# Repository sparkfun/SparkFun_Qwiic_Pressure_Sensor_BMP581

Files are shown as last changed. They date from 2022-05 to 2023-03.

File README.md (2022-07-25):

SparkFun Pressure Sensor - BMP581 (Qwiic) 
=========================================

<table class="table table-hover table-striped table-bordered">
  <tr align="center">
    <td><a href="https://www.sparkfun.com/products/20170">SparkFun Pressure Sensor - BMP581 (Qwiic)</a></td>
    <td><a href="https://www.sparkfun.com/products/20171">SparkFun Micro Pressure Sensor - BMP581 (Qwiic)</a></td>
  </tr>
  <tr align="center">
    <td><a href="https://www.sparkfun.com/products/20170"><i>SparkFun Pressure Sensor - BMP581 (Qwiic)</i></a></td>
    <td><a href="https://www.sparkfun.com/products/20171"><i>SparkFun Micro Pressure Sensor - BMP581 (Qwiic)</i></a></td>
  </tr>
</table>

The SparkFun Pressure Sensor - BMP581 (Qwiic) and Micro Pressure Sensor - BMP581 (Qwiic) features the BMP581 pressure sensor from Bosch Sensortec. The BMP581 boasts exceptional resolution (down to 1/64 Pa) and accuracy  and uses on-chip linearization and temperature compensation to provide true absolute data for pressure and temperature. 

The BMP581 has a wide pressure sensing range (30 to 125 kPa) with excellent accuracy across the sensing range (&plusmn; 0.5 hPa (max)) as well as output data rates up to 622 Hz. The sensor includes a configurable oversampling setting, FIFO buffer for storing up to 32 pressure samples, programmable low-pass filtering and even 6-bytes of user-programmable non-volatile memory. All of this allows you to customize the performance based on your application's requirements. Even without filtering, the BMP581 has very low noise (< 0.1Pa RMS).

Repository Contents
-------------------
* **/Documents** - Datasheet
* **/Hardware** - Eagle design files (.brd, .sch)
* **/Production** - Production panel files (.brd)

Documentation
-------------
* **[Hookup Guide](https://learn.sparkfun.com/tutorials/qwiic-pressure-sensor-bmp581-hookup-guide)** - Basic Hookup Guide for the SparkFun Pressure Sensor - BMP581 (Qwiic)
* **[BMP581 Arduino Library](https://github.com/sparkfun/SparkFun_BMP581_Arduino_Library)** - Arduino library for the BMP581 based off the Bosch API.

Product Versions
----------------
* [SEN-20170](https://www.sparkfun.com/products/20170) - Standard Size Initial Release.
* [SEN-20171](https://www.sparkfun.com/products/20171) - Micro Size Initial Release.

License Information
-------------------

This product is _**open source**_! 

Please review the LICENSE.md file for license information.

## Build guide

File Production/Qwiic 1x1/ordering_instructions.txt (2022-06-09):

panel size, 169x117mm
PCB thickness, 1.6mm
number of layers, 2
soldermask color, Red
silkscreen color, White
oz copper, 1oz
finish, HASL lead free
stencils, top
pcs per panel, 24
min trace width, 0.1778mm / 0.0070in
min drill size, 0.3048mm / 0.0120in

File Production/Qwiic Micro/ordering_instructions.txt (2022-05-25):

panel size, 79x170mm
PCB thickness, 1.6mm
number of layers, 2
soldermask color, Red
silkscreen color, White
oz copper, 1oz
finish, HASL lead free
stencils, top
pcs per panel, 64
min trace width, 0.1270mm / 0.0050in
min drill size, 0.3048mm / 0.0120in

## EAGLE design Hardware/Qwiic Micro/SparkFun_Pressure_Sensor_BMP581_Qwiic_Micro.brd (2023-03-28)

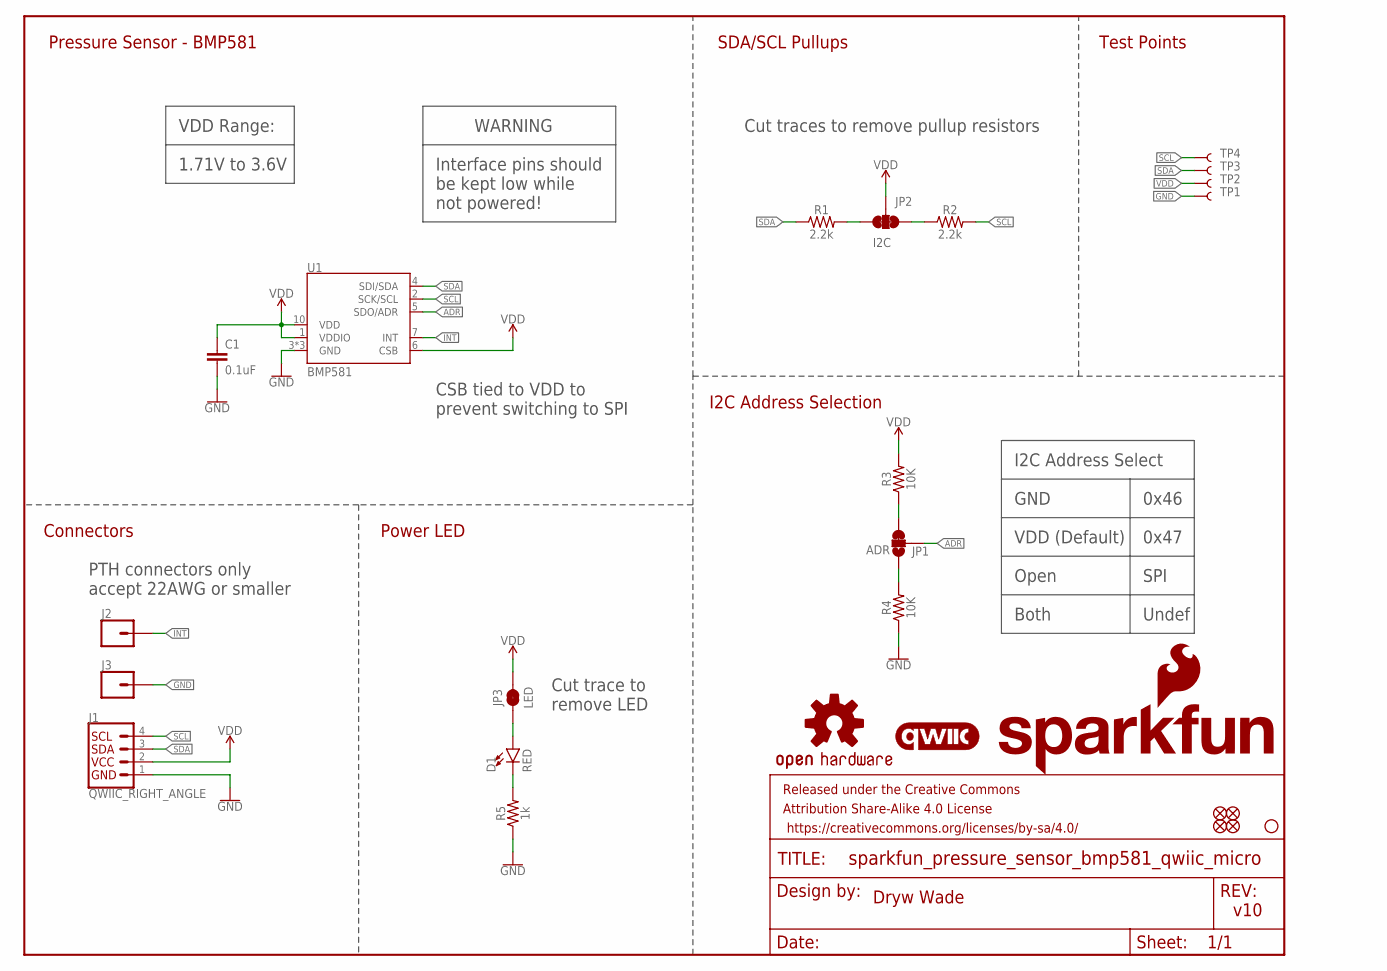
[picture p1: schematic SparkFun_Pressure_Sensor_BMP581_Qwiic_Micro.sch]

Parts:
C1: 0.1uF; 0402-TIGHT
D1: RED; LED-0402
FD1, FD2, FD3, FD4: FIDUCIALUFIDUCIAL; FIDUCIAL-MICRO
FRAME1: FRAME-LETTER; CREATIVE_COMMONS
H1: STAND-OFF
J1: QWIIC_RIGHT_ANGLE; JST04_1MM_RA
J2, J3: CONN_01_1MM; 1X01_1MM_NO_SILK
JP1: ADR; SMT-JUMPER_3_1-NC_TRACE_SILK
JP2: I2C; SMT-JUMPER_3_2-NC_TRACE_SILK
JP3: LED; SMT-JUMPER_2_NC_TRACE_SILK
LOGO1: OSHW-LOGOMINI; OSHW-LOGO-MINI
LOGO2: SFE_LOGO_FLAME.1_INCH; SFE_LOGO_FLAME_.1
LOGO3: QWIIC_LOGO_3MM; QWIIC_3MM
LOGO4: SFE_LOGO_NAMEBLANK; BLANK
R1, R2: 2.2k; 0402-TIGHT
R3, R4: 10K; 0402-TIGHT
R5: 1k; 0402-TIGHT
TP1, TP2, TP3, TP4: TEST-POINT3; PAD.03X.03
U1: BMP581

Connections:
ADR: JP1.2, U1.5 (SDO/ADR)
GND: C1.2, J1.1, J3.1, R4.1, R5.1, TP1.1, U1.3 (GND), U1.8 (GND), U1.9 (GND)
INT: J2.1, U1.7 (INT)
unnamed: JP1.3, R3.1
unnamed: JP1.1, R4.2
unnamed: JP2.1, R2.1
unnamed: JP2.3, R1.2
unnamed: D1.A, JP3.1
unnamed: D1.C, R5.2
SCL: J1.4, R2.2, TP4.1, U1.2 (SCK/SCL)
SDA: J1.3, R1.1, TP3.1, U1.4 (SDI/SDA)
VDD: C1.1, J1.2, JP2.2, JP3.2, R3.2, TP2.1, U1.1 (VDDIO), U1.6 (CSB), U1.10 (VDD)

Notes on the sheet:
Dryw Wade
v10
Pressure Sensor - BMP581
I2C Address Selection
I2C Address Select
GND
VDD (Default)
0x46
0x47
Open
Both
SPI
Undef
VDD Range:
1.71V to 3.6V
WARNING
Interface pins should be kept low while not powered!
Connectors
SDA/SCL Pullups
Cut traces to remove pullup resistors
Test Points
Power LED
Cut trace to remove LED
PTH connectors only accept 22AWG or smaller
CSB tied to VDD to prevent switching to SPI

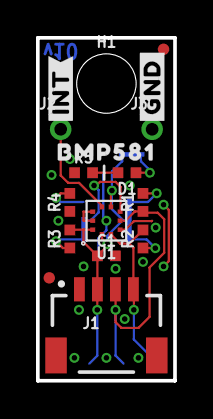
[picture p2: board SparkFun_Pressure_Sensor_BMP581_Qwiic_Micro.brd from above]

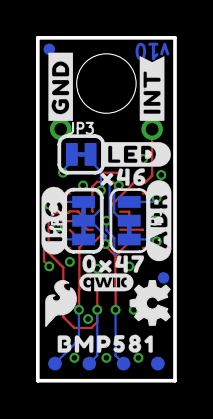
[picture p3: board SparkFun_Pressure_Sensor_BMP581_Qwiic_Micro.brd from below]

Board: 2 copper layers, 7.6 x 19.1 mm, 39 parts (20 on the bottom side), 12 nets.

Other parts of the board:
U$1, U$2: BMP5810
U$3: #I2C#0
U$4: #ADR#0
U$5, U$6: #GND#0
U$7, U$8: #INT#0
U$9: #LED#0
U$10: X460
U$11: 0X470

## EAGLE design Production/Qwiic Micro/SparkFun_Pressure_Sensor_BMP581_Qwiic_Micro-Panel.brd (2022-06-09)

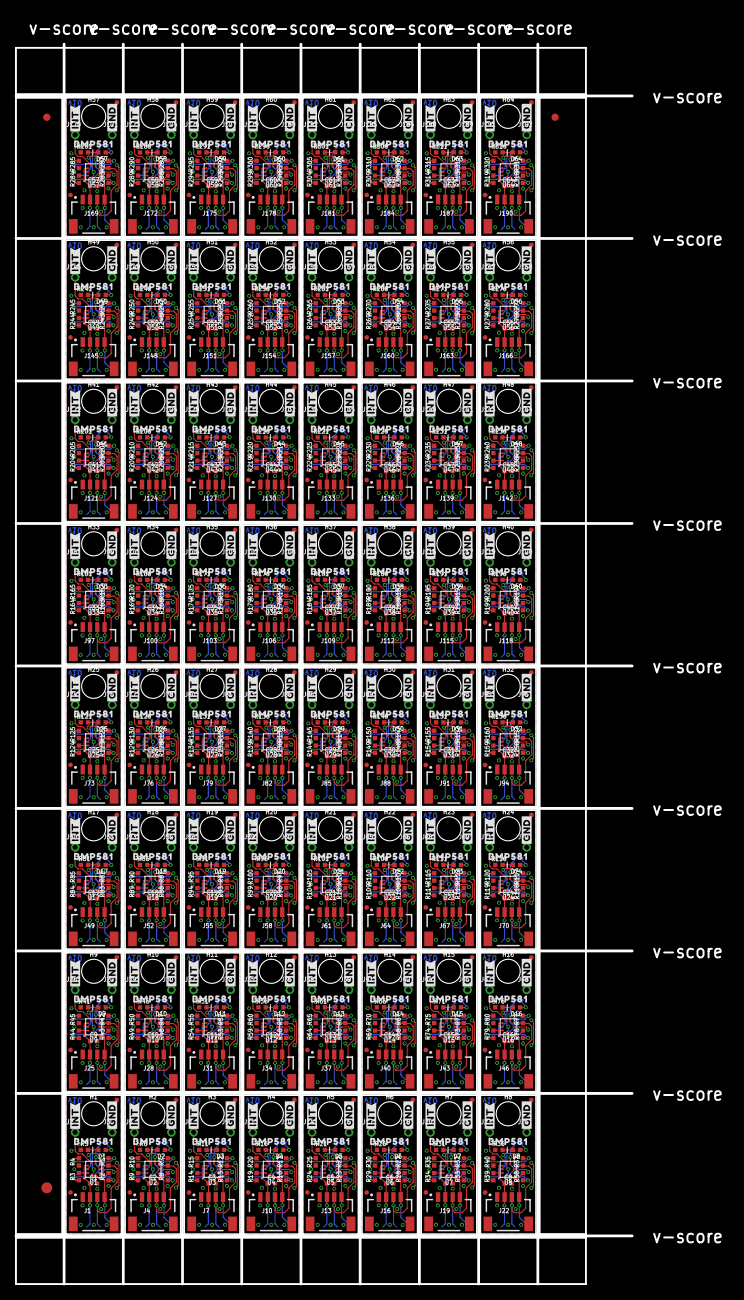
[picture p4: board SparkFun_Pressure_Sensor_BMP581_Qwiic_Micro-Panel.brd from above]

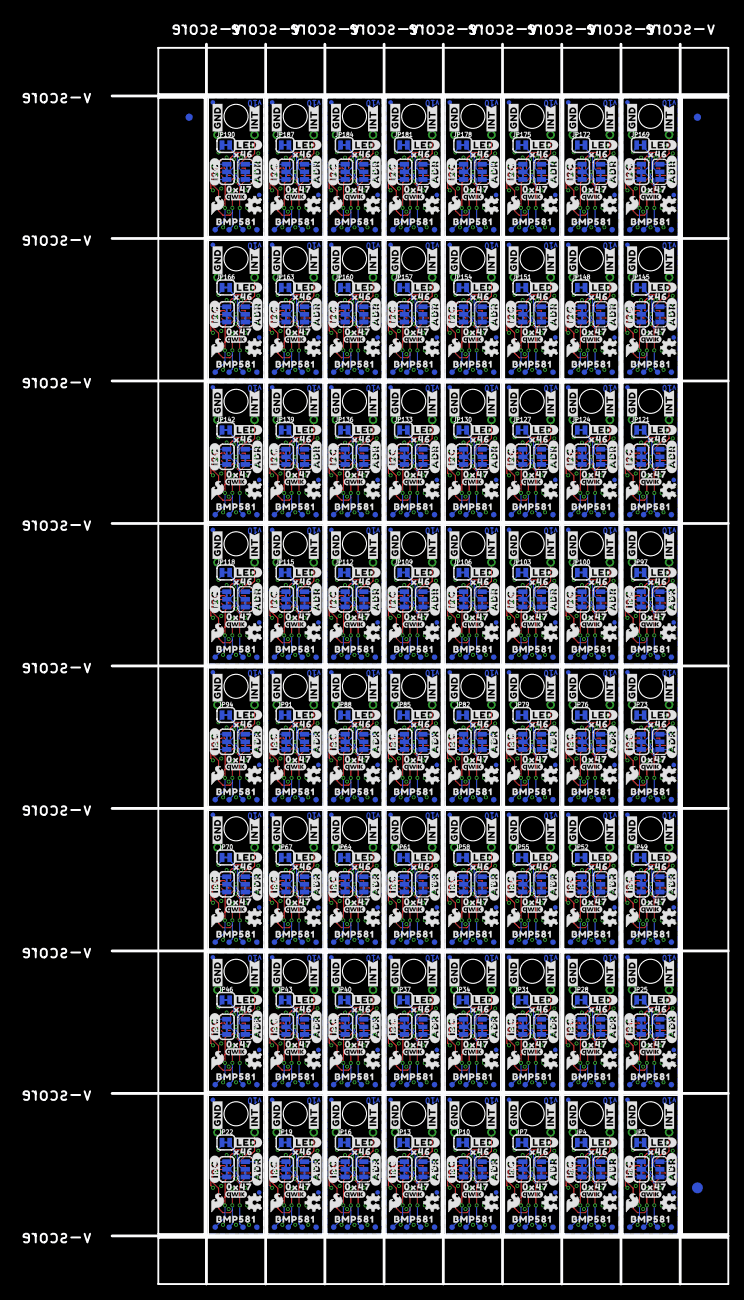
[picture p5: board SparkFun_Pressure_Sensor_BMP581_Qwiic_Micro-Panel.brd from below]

Board: 2 copper layers, 84.6 x 170.2 mm, 2502 parts (1283 on the bottom side), 768 nets.

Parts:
C1, C2, C3, C4, C5, C6, C7, C8, C9, C10, C11, C12, C13, C14, C15, C16, C17, C18, C19, C20, C21, C22, C23, C24, C25, C26, C27, C28, C29, C30, C31, C32, C33, C34, C35, C36, C37, C38, C39, C40, C41, C42, C43, C44, C45, C46, C47, C48, C49, C50, C51, C52, C53, C54, C55, C56, C57, C58, C59, C60, C61, C62, C63, C64: 0.1uF; 0402-TIGHT
D1, D2, D3, D4, D5, D6, D7, D8, D9, D10, D11, D12, D13, D14, D15, D16, D17, D18, D19, D20, D21, D22, D23, D24, D25, D26, D27, D28, D29, D30, D31, D32, D33, D34, D35, D36, D37, D38, D39, D40, D41, D42, D43, D44, D45, D46, D47, D48, D49, D50, D51, D52, D53, D54, D55, D56, D57, D58, D59, D60, D61, D62, D63, D64: RED; LED-0402
E$1, E$2, E$3, E$4: FIDUCIAL-1X2
E$5, E$6: FIDUCIAL-1.5X3
FD1, FD2, FD3, FD4, FD5, FD6, FD7, FD8, FD9, FD10, FD11, FD12, FD13, FD14, FD15, FD16, FD17, FD18, FD19, FD20, FD21, FD22, FD23, FD24, FD25, FD26, FD27, FD28, FD29, FD30, FD31, FD32, FD33, FD34, FD35, FD36, FD37, FD38, FD39, FD40, FD41, FD42, FD43, FD44, FD45, FD46, FD47, FD48, FD49, FD50, FD51, FD52, FD53, FD54, FD55, FD56, FD57, FD58, FD59, FD60, FD61, FD62, FD63, FD64, FD65, FD66, FD67, FD68, FD69, FD70, FD71, FD72, FD73, FD74, FD75, FD76, FD77, FD78, FD79, FD80, FD81, FD82, FD83, FD84, FD85, FD86, FD87, FD88, FD89, FD90, FD91, FD92, FD93, FD94, FD95, FD96, FD97, FD98, FD99, FD100, FD101, FD102, FD103, FD104, FD105, FD106, FD107, FD108, FD109, FD110, FD111, FD112, FD113, FD114, FD115, FD116, FD117, FD118, FD119, FD120, FD121, FD122, FD123, FD124, FD125, FD126, FD127, FD128, FD129, FD130, FD131, FD132, FD133, FD134, FD135, FD136, FD137, FD138, FD139, FD140, FD141, FD142, FD143, FD144, FD145, FD146, FD147, FD148, FD149, FD150, FD151, FD152, FD153, FD154, FD155, FD156, FD157, FD158, FD159, FD160, FD161, FD162, FD163, FD164, FD165, FD166, FD167, FD168, FD169, FD170, FD171, FD172, FD173, FD174, FD175, FD176, FD177, FD178, FD179, FD180, FD181, FD182, FD183, FD184, FD185, FD186, FD187, FD188, FD189, FD190, FD191, FD192, FD193, FD194, FD195, FD196, FD197, FD198, FD199, FD200, FD201, FD202, FD203, FD204, FD205, FD206, FD207, FD208, FD209, FD210, FD211, FD212, FD213, FD214, FD215, FD216, FD217, FD218, FD219, FD220, FD221, FD222, FD223, FD224, FD225, FD226, FD227, FD228, FD229, FD230, FD231, FD232, FD233, FD234, FD235, FD236, FD237, FD238, FD239, FD240, FD241, FD242, FD243, FD244, FD245, FD246, FD247, FD248, FD249, FD250, FD251, FD252, FD253, FD254, FD255, FD256: FIDUCIALUFIDUCIAL; FIDUCIAL-MICRO
FRAME1, FRAME2, FRAME3, FRAME4, FRAME5, FRAME6, FRAME7, FRAME8, FRAME9, FRAME10, FRAME11, FRAME12, FRAME13, FRAME14, FRAME15, FRAME16, FRAME17, FRAME18, FRAME19, FRAME20, FRAME21, FRAME22, FRAME23, FRAME24, FRAME25, FRAME26, FRAME27, FRAME28, FRAME29, FRAME30, FRAME31, FRAME32, FRAME33, FRAME34, FRAME35, FRAME36, FRAME37, FRAME38, FRAME39, FRAME40, FRAME41, FRAME42, FRAME43, FRAME44, FRAME45, FRAME46, FRAME47, FRAME48, FRAME49, FRAME50, FRAME51, FRAME52, FRAME53, FRAME54, FRAME55, FRAME56, FRAME57, FRAME58, FRAME59, FRAME60, FRAME61, FRAME62, FRAME63, FRAME64: FRAME-LETTER; CREATIVE_COMMONS
H1, H2, H3, H4, H5, H6, H7, H8, H9, H10, H11, H12, H13, H14, H15, H16, H17, H18, H19, H20, H21, H22, H23, H24, H25, H26, H27, H28, H29, H30, H31, H32, H33, H34, H35, H36, H37, H38, H39, H40, H41, H42, H43, H44, H45, H46, H47, H48, H49, H50, H51, H52, H53, H54, H55, H56, H57, H58, H59, H60, H61, H62, H63, H64: STAND-OFF
J1, J4, J7, J10, J13, J16, J19, J22, J25, J28, J31, J34, J37, J40, J43, J46, J49, J52, J55, J58, J61, J64, J67, J70, J73, J76, J79, J82, J85, J88, J91, J94, J97, J100, J103, J106, J109, J112, J115, J118, J121, J124, J127, J130, J133, J136, J139, J142, J145, J148, J151, J154, J157, J160, J163, J166, J169, J172, J175, J178, J181, J184, J187, J190: QWIIC_RIGHT_ANGLE; JST04_1MM_RA
J2, J3, J5, J6, J8, J9, J11, J12, J14, J15, J17, J18, J20, J21, J23, J24, J26, J27, J29, J30, J32, J33, J35, J36, J38, J39, J41, J42, J44, J45, J47, J48, J50, J51, J53, J54, J56, J57, J59, J60, J62, J63, J65, J66, J68, J69, J71, J72, J74, J75, J77, J78, J80, J81, J83, J84, J86, J87, J89, J90, J92, J93, J95, J96, J98, J99, J101, J102, J104, J105, J107, J108, J110, J111, J113, J114, J116, J117, J119, J120, J122, J123, J125, J126, J128, J129, J131, J132, J134, J135, J137, J138, J140, J141, J143, J144, J146, J147, J149, J150, J152, J153, J155, J156, J158, J159, J161, J162, J164, J165, J167, J168, J170, J171, J173, J174, J176, J177, J179, J180, J182, J183, J185, J186, J188, J189, J191, J192: 1X01_1MM_NO_SILK
JP1, JP6, JP9, JP12, JP15, JP18, JP21, JP24, JP27, JP30, JP33, JP36, JP39, JP42, JP45, JP48, JP51, JP54, JP57, JP60, JP63, JP66, JP69, JP72, JP75, JP78, JP81, JP84, JP87, JP90, JP93, JP96, JP99, JP102, JP105, JP108, JP111, JP114, JP117, JP120, JP123, JP126, JP129, JP132, JP135, JP138, JP141, JP144, JP147, JP150, JP153, JP156, JP159, JP162, JP165, JP168, JP171, JP174, JP177, JP180, JP183, JP186, JP189, JP192: ADR; SMT-JUMPER_3_1-NC_TRACE_SILK
JP2, JP5, JP8, JP11, JP14, JP17, JP20, JP23, JP26, JP29, JP32, JP35, JP38, JP41, JP44, JP47, JP50, JP53, JP56, JP59, JP62, JP65, JP68, JP71, JP74, JP77, JP80, JP83, JP86, JP89, JP92, JP95, JP98, JP101, JP104, JP107, JP110, JP113, JP116, JP119, JP122, JP125, JP128, JP131, JP134, JP137, JP140, JP143, JP146, JP149, JP152, JP155, JP158, JP161, JP164, JP167, JP170, JP173, JP176, JP179, JP182, JP185, JP188, JP191: I2C; SMT-JUMPER_3_2-NC_TRACE_SILK
JP3, JP4, JP7, JP10, JP13, JP16, JP19, JP22, JP25, JP28, JP31, JP34, JP37, JP40, JP43, JP46, JP49, JP52, JP55, JP58, JP61, JP64, JP67, JP70, JP73, JP76, JP79, JP82, JP85, JP88, JP91, JP94, JP97, JP100, JP103, JP106, JP109, JP112, JP115, JP118, JP121, JP124, JP127, JP130, JP133, JP136, JP139, JP142, JP145, JP148, JP151, JP154, JP157, JP160, JP163, JP166, JP169, JP172, JP175, JP178, JP181, JP184, JP187, JP190: LED; SMT-JUMPER_2_NC_TRACE_SILK
LOGO1, LOGO5, LOGO9, LOGO13, LOGO17, LOGO21, LOGO25, LOGO29, LOGO33, LOGO37, LOGO41, LOGO45, LOGO49, LOGO53, LOGO57, LOGO61, LOGO65, LOGO69, LOGO73, LOGO77, LOGO81, LOGO85, LOGO89, LOGO93, LOGO97, LOGO101, LOGO105, LOGO109, LOGO113, LOGO117, LOGO121, LOGO125, LOGO129, LOGO133, LOGO137, LOGO141, LOGO145, LOGO149, LOGO153, LOGO157, LOGO161, LOGO165, LOGO169, LOGO173, LOGO177, LOGO181, LOGO185, LOGO189, LOGO193, LOGO197, LOGO201, LOGO205, LOGO209, LOGO213, LOGO217, LOGO221, LOGO225, LOGO229, LOGO233, LOGO237, LOGO241, LOGO245, LOGO249, LOGO253: OSHW-LOGOMINI; OSHW-LOGO-MINI
LOGO2, LOGO6, LOGO10, LOGO14, LOGO18, LOGO22, LOGO26, LOGO30, LOGO34, LOGO38, LOGO42, LOGO46, LOGO50, LOGO54, LOGO58, LOGO62, LOGO66, LOGO70, LOGO74, LOGO78, LOGO82, LOGO86, LOGO90, LOGO94, LOGO98, LOGO102, LOGO106, LOGO110, LOGO114, LOGO118, LOGO122, LOGO126, LOGO130, LOGO134, LOGO138, LOGO142, LOGO146, LOGO150, LOGO154, LOGO158, LOGO162, LOGO166, LOGO170, LOGO174, LOGO178, LOGO182, LOGO186, LOGO190, LOGO194, LOGO198, LOGO202, LOGO206, LOGO210, LOGO214, LOGO218, LOGO222, LOGO226, LOGO230, LOGO234, LOGO238, LOGO242, LOGO246, LOGO250, LOGO254: SFE_LOGO_FLAME.1_INCH; SFE_LOGO_FLAME_.1
LOGO3, LOGO7, LOGO11, LOGO15, LOGO19, LOGO23, LOGO27, LOGO31, LOGO35, LOGO39, LOGO43, LOGO47, LOGO51, LOGO55, LOGO59, LOGO63, LOGO67, LOGO71, LOGO75, LOGO79, LOGO83, LOGO87, LOGO91, LOGO95, LOGO99, LOGO103, LOGO107, LOGO111, LOGO115, LOGO119, LOGO123, LOGO127, LOGO131, LOGO135, LOGO139, LOGO143, LOGO147, LOGO151, LOGO155, LOGO159, LOGO163, LOGO167, LOGO171, LOGO175, LOGO179, LOGO183, LOGO187, LOGO191, LOGO195, LOGO199, LOGO203, LOGO207, LOGO211, LOGO215, LOGO219, LOGO223, LOGO227, LOGO231, LOGO235, LOGO239, LOGO243, LOGO247, LOGO251, LOGO255: QWIIC_LOGO_3MM; QWIIC_3MM
LOGO4, LOGO8, LOGO12, LOGO16, LOGO20, LOGO24, LOGO28, LOGO32, LOGO36, LOGO40, LOGO44, LOGO48, LOGO52, LOGO56, LOGO60, LOGO64, LOGO68, LOGO72, LOGO76, LOGO80, LOGO84, LOGO88, LOGO92, LOGO96, LOGO100, LOGO104, LOGO108, LOGO112, LOGO116, LOGO120, LOGO124, LOGO128, LOGO132, LOGO136, LOGO140, LOGO144, LOGO148, LOGO152, LOGO156, LOGO160, LOGO164, LOGO168, LOGO172, LOGO176, LOGO180, LOGO184, LOGO188, LOGO192, LOGO196, LOGO200, LOGO204, LOGO208, LOGO212, LOGO216, LOGO220, LOGO224, LOGO228, LOGO232, LOGO236, LOGO240, LOGO244, LOGO248, LOGO252, LOGO256: SFE_LOGO_NAMEBLANK; BLANK
R1, R2, R7, R8, R12, R13, R17, R18, R22, R23, R27, R28, R32, R33, R37, R38, R42, R43, R47, R48, R52, R53, R57, R58, R62, R63, R67, R68, R72, R73, R77, R78, R82, R83, R87, R88, R92, R93, R97, R98, R102, R103, R107, R108, R112, R113, R117, R118, R122, R123, R127, R128, R132, R133, R137, R138, R142, R143, R147, R148, R152, R153, R157, R158, R162, R163, R167, R168, R172, R173, R177, R178, R182, R183, R187, R188, R192, R193, R197, R198, R202, R203, R207, R208, R212, R213, R217, R218, R222, R223, R227, R228, R232, R233, R237, R238, R242, R243, R247, R248, R252, R253, R257, R258, R262, R263, R267, R268, R272, R273, R277, R278, R282, R283, R287, R288, R292, R293, R297, R298, R302, R303, R307, R308, R312, R313, R317, R318: 2.2k; 0402-TIGHT
R3, R4, R9, R10, R14, R15, R19, R20, R24, R25, R29, R30, R34, R35, R39, R40, R44, R45, R49, R50, R54, R55, R59, R60, R64, R65, R69, R70, R74, R75, R79, R80, R84, R85, R89, R90, R94, R95, R99, R100, R104, R105, R109, R110, R114, R115, R119, R120, R124, R125, R129, R130, R134, R135, R139, R140, R144, R145, R149, R150, R154, R155, R159, R160, R164, R165, R169, R170, R174, R175, R179, R180, R184, R185, R189, R190, R194, R195, R199, R200, R204, R205, R209, R210, R214, R215, R219, R220, R224, R225, R229, R230, R234, R235, R239, R240, R244, R245, R249, R250, R254, R255, R259, R260, R264, R265, R269, R270, R274, R275, R279, R280, R284, R285, R289, R290, R294, R295, R299, R300, R304, R305, R309, R310, R314, R315, R319, R320: 10K; 0402-TIGHT
R5, R6, R11, R16, R21, R26, R31, R36, R41, R46, R51, R56, R61, R66, R71, R76, R81, R86, R91, R96, R101, R106, R111, R116, R121, R126, R131, R136, R141, R146, R151, R156, R161, R166, R171, R176, R181, R186, R191, R196, R201, R206, R211, R216, R221, R226, R231, R236, R241, R246, R251, R256, R261, R266, R271, R276, R281, R286, R291, R296, R301, R306, R311, R316: 1k; 0402-TIGHT
TP1, TP2, TP3, TP4, TP5, TP6, TP7, TP8, TP9, TP10, TP11, TP12, TP13, TP14, TP15, TP16, TP17, TP18, TP19, TP20, TP21, TP22, TP23, TP24, TP25, TP26, TP27, TP28, TP29, TP30, TP31, TP32, TP33, TP34, TP35, TP36, TP37, TP38, TP39, TP40, TP41, TP42, TP43, TP44, TP45, TP46, TP47, TP48, TP49, TP50, TP51, TP52, TP53, TP54, TP55, TP56, TP57, TP58, TP59, TP60, TP61, TP62, TP63, TP64, TP65, TP66, TP67, TP68, TP69, TP70, TP71, TP72, TP73, TP74, TP75, TP76, TP77, TP78, TP79, TP80, TP81, TP82, TP83, TP84, TP85, TP86, TP87, TP88, TP89, TP90, TP91, TP92, TP93, TP94, TP95, TP96, TP97, TP98, TP99, TP100, TP101, TP102, TP103, TP104, TP105, TP106, TP107, TP108, TP109, TP110, TP111, TP112, TP113, TP114, TP115, TP116, TP117, TP118, TP119, TP120, TP121, TP122, TP123, TP124, TP125, TP126, TP127, TP128, TP129, TP130, TP131, TP132, TP133, TP134, TP135, TP136, TP137, TP138, TP139, TP140, TP141, TP142, TP143, TP144, TP145, TP146, TP147, TP148, TP149, TP150, TP151, TP152, TP153, TP154, TP155, TP156, TP157, TP158, TP159, TP160, TP161, TP162, TP163, TP164, TP165, TP166, TP167, TP168, TP169, TP170, TP171, TP172, TP173, TP174, TP175, TP176, TP177, TP178, TP179, TP180, TP181, TP182, TP183, TP184, TP185, TP186, TP187, TP188, TP189, TP190, TP191, TP192, TP193, TP194, TP195, TP196, TP197, TP198, TP199, TP200, TP201, TP202, TP203, TP204, TP205, TP206, TP207, TP208, TP209, TP210, TP211, TP212, TP213, TP214, TP215, TP216, TP217, TP218, TP219, TP220, TP221, TP222, TP223, TP224, TP225, TP226, TP227, TP228, TP229, TP230, TP231, TP232, TP233, TP234, TP235, TP236, TP237, TP238, TP239, TP240, TP241, TP242, TP243, TP244, TP245, TP246, TP247, TP248, TP249, TP250, TP251, TP252, TP253, TP254, TP255, TP256: TEST-POINT3; PAD.03X.03
U1, U2, U3, U4, U5, U6, U7, U8, U9, U10, U11, U12, U13, U14, U15, U16, U17, U18, U19, U20, U21, U22, U23, U24, U25, U26, U27, U28, U29, U30, U31, U32, U33, U34, U35, U36, U37, U38, U39, U40, U41, U42, U43, U44, U45, U46, U47, U48, U49, U50, U51, U52, U53, U54, U55, U56, U57, U58, U59, U60, U61, U62, U63, U64: BMP581
U$1, U$2, U$16, U$17, U$27, U$28, U$38, U$39, U$49, U$50, U$60, U$61, U$71, U$72, U$82, U$83, U$93, U$94, U$104, U$105, U$115, U$116, U$126, U$127, U$137, U$138, U$148, U$149, U$159, U$160, U$170, U$171, U$181, U$182, U$192, U$193, U$203, U$204, U$214, U$215, U$225, U$226, U$236, U$237, U$247, U$248, U$258, U$259, U$269, U$270, U$280, U$281, U$291, U$292, U$302, U$303, U$313, U$314, U$324, U$325, U$335, U$336, U$346, U$347, U$357, U$358, U$368, U$369, U$379, U$380, U$390, U$391, U$401, U$402, U$412, U$413, U$423, U$424, U$434, U$435, U$445, U$446, U$456, U$457, U$467, U$468, U$478, U$479, U$489, U$490, U$500, U$501, U$511, U$512, U$522, U$523, U$533, U$534, U$544, U$545, U$555, U$556, U$566, U$567, U$577, U$578, U$588, U$589, U$599, U$600, U$610, U$611, U$621, U$622, U$632, U$633, U$643, U$644, U$654, U$655, U$665, U$666, U$676, U$677, U$687, U$688, U$698, U$699: BMP5810
U$3, U$18, U$29, U$40, U$51, U$62, U$73, U$84, U$95, U$106, U$117, U$128, U$139, U$150, U$161, U$172, U$183, U$194, U$205, U$216, U$227, U$238, U$249, U$260, U$271, U$282, U$293, U$304, U$315, U$326, U$337, U$348, U$359, U$370, U$381, U$392, U$403, U$414, U$425, U$436, U$447, U$458, U$469, U$480, U$491, U$502, U$513, U$524, U$535, U$546, U$557, U$568, U$579, U$590, U$601, U$612, U$623, U$634, U$645, U$656, U$667, U$678, U$689, U$700: #I2C#0
U$4, U$19, U$30, U$41, U$52, U$63, U$74, U$85, U$96, U$107, U$118, U$129, U$140, U$151, U$162, U$173, U$184, U$195, U$206, U$217, U$228, U$239, U$250, U$261, U$272, U$283, U$294, U$305, U$316, U$327, U$338, U$349, U$360, U$371, U$382, U$393, U$404, U$415, U$426, U$437, U$448, U$459, U$470, U$481, U$492, U$503, U$514, U$525, U$536, U$547, U$558, U$569, U$580, U$591, U$602, U$613, U$624, U$635, U$646, U$657, U$668, U$679, U$690, U$701: #ADR#0
U$5, U$6, U$12, U$13, U$23, U$24, U$34, U$35, U$45, U$46, U$56, U$57, U$67, U$68, U$78, U$79, U$89, U$90, U$100, U$101, U$111, U$112, U$122, U$123, U$133, U$134, U$144, U$145, U$155, U$156, U$166, U$167, U$177, U$178, U$188, U$189, U$199, U$200, U$210, U$211, U$221, U$222, U$232, U$233, U$243, U$244, U$254, U$255, U$265, U$266, U$276, U$277, U$287, U$288, U$298, U$299, U$309, U$310, U$320, U$321, U$331, U$332, U$342, U$343, U$353, U$354, U$364, U$365, U$375, U$376, U$386, U$387, U$397, U$398, U$408, U$409, U$419, U$420, U$430, U$431, U$441, U$442, U$452, U$453, U$463, U$464, U$474, U$475, U$485, U$486, U$496, U$497, U$507, U$508, U$518, U$519, U$529, U$530, U$540, U$541, U$551, U$552, U$562, U$563, U$573, U$574, U$584, U$585, U$595, U$596, U$606, U$607, U$617, U$618, U$628, U$629, U$639, U$640, U$650, U$651, U$661, U$662, U$672, U$673, U$683, U$684, U$694, U$695: #GND#0
U$7, U$8, U$14, U$15, U$25, U$26, U$36, U$37, U$47, U$48, U$58, U$59, U$69, U$70, U$80, U$81, U$91, U$92, U$102, U$103, U$113, U$114, U$124, U$125, U$135, U$136, U$146, U$147, U$157, U$158, U$168, U$169, U$179, U$180, U$190, U$191, U$201, U$202, U$212, U$213, U$223, U$224, U$234, U$235, U$245, U$246, U$256, U$257, U$267, U$268, U$278, U$279, U$289, U$290, U$300, U$301, U$311, U$312, U$322, U$323, U$333, U$334, U$344, U$345, U$355, U$356, U$366, U$367, U$377, U$378, U$388, U$389, U$399, U$400, U$410, U$411, U$421, U$422, U$432, U$433, U$443, U$444, U$454, U$455, U$465, U$466, U$476, U$477, U$487, U$488, U$498, U$499, U$509, U$510, U$520, U$521, U$531, U$532, U$542, U$543, U$553, U$554, U$564, U$565, U$575, U$576, U$586, U$587, U$597, U$598, U$608, U$609, U$619, U$620, U$630, U$631, U$641, U$642, U$652, U$653, U$663, U$664, U$674, U$675, U$685, U$686, U$696, U$697: #INT#0
U$9, U$20, U$31, U$42, U$53, U$64, U$75, U$86, U$97, U$108, U$119, U$130, U$141, U$152, U$163, U$174, U$185, U$196, U$207, U$218, U$229, U$240, U$251, U$262, U$273, U$284, U$295, U$306, U$317, U$328, U$339, U$350, U$361, U$372, U$383, U$394, U$405, U$416, U$427, U$438, U$449, U$460, U$471, U$482, U$493, U$504, U$515, U$526, U$537, U$548, U$559, U$570, U$581, U$592, U$603, U$614, U$625, U$636, U$647, U$658, U$669, U$680, U$691, U$702: #LED#0
U$10, U$21, U$32, U$43, U$54, U$65, U$76, U$87, U$98, U$109, U$120, U$131, U$142, U$153, U$164, U$175, U$186, U$197, U$208, U$219, U$230, U$241, U$252, U$263, U$274, U$285, U$296, U$307, U$318, U$329, U$340, U$351, U$362, U$373, U$384, U$395, U$406, U$417, U$428, U$439, U$450, U$461, U$472, U$483, U$494, U$505, U$516, U$527, U$538, U$549, U$560, U$571, U$582, U$593, U$604, U$615, U$626, U$637, U$648, U$659, U$670, U$681, U$692, U$703: X460
U$11, U$22, U$33, U$44, U$55, U$66, U$77, U$88, U$99, U$110, U$121, U$132, U$143, U$154, U$165, U$176, U$187, U$198, U$209, U$220, U$231, U$242, U$253, U$264, U$275, U$286, U$297, U$308, U$319, U$330, U$341, U$352, U$363, U$374, U$385, U$396, U$407, U$418, U$429, U$440, U$451, U$462, U$473, U$484, U$495, U$506, U$517, U$528, U$539, U$550, U$561, U$572, U$583, U$594, U$605, U$616, U$627, U$638, U$649, U$660, U$671, U$682, U$693, U$704: 0X470

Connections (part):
ADR: JP1.2, U1.5
ADR1: JP6.2, U2.5
ADR2: JP9.2, U3.5
ADR3: JP12.2, U4.5
ADR4: JP15.2, U5.5
ADR5: JP18.2, U6.5
ADR6: JP21.2, U7.5
ADR7: JP24.2, U8.5
ADR8: JP27.2, U9.5
ADR9: JP30.2, U10.5
ADR10: JP33.2, U11.5
ADR11: JP36.2, U12.5
ADR12: JP39.2, U13.5
ADR13: JP42.2, U14.5
ADR14: JP45.2, U15.5
ADR15: JP48.2, U16.5
ADR16: JP51.2, U17.5
ADR17: JP54.2, U18.5
ADR18: JP57.2, U19.5
ADR19: JP60.2, U20.5
ADR20: JP63.2, U21.5
ADR21: JP66.2, U22.5
ADR22: JP69.2, U23.5
ADR23: JP72.2, U24.5
ADR24: JP75.2, U25.5
ADR25: JP78.2, U26.5
ADR26: JP81.2, U27.5
ADR27: JP84.2, U28.5
ADR28: JP87.2, U29.5
ADR29: JP90.2, U30.5
ADR30: JP93.2, U31.5
ADR31: JP96.2, U32.5
ADR32: JP99.2, U33.5
ADR33: JP102.2, U34.5
ADR34: JP105.2, U35.5
ADR35: JP108.2, U36.5
ADR36: JP111.2, U37.5
ADR37: JP114.2, U38.5
ADR38: JP117.2, U39.5
ADR39: JP120.2, U40.5
ADR40: JP123.2, U41.5
ADR41: JP126.2, U42.5
ADR42: JP129.2, U43.5
ADR43: JP132.2, U44.5
ADR44: JP135.2, U45.5
ADR45: JP138.2, U46.5
ADR46: JP141.2, U47.5
ADR47: JP144.2, U48.5
ADR48: JP147.2, U49.5
ADR49: JP150.2, U50.5
ADR50: JP153.2, U51.5
ADR51: JP156.2, U52.5
ADR52: JP159.2, U53.5
ADR53: JP162.2, U54.5
ADR54: JP165.2, U55.5
ADR55: JP168.2, U56.5
ADR56: JP171.2, U57.5
ADR57: JP174.2, U58.5
ADR58: JP177.2, U59.5
ADR59: JP180.2, U60.5
ADR60: JP183.2, U61.5
ADR61: JP186.2, U62.5
ADR62: JP189.2, U63.5
ADR63: JP192.2, U64.5
GND: C1.2, J1.1, J3.1, R4.1, R5.1, TP1.1, U1.3, U1.8, U1.9
GND1: C2.2, J4.1, J6.1, R6.1, R10.1, TP5.1, U2.3, U2.8, U2.9
GND2: C3.2, J7.1, J9.1, R11.1, R15.1, TP9.1, U3.3, U3.8, U3.9
GND3: C4.2, J10.1, J12.1, R16.1, R20.1, TP13.1, U4.3, U4.8, U4.9
GND4: C5.2, J13.1, J15.1, R21.1, R25.1, TP17.1, U5.3, U5.8, U5.9
GND5: C6.2, J16.1, J18.1, R26.1, R30.1, TP21.1, U6.3, U6.8, U6.9
GND6: C7.2, J19.1, J21.1, R31.1, R35.1, TP25.1, U7.3, U7.8, U7.9
GND7: C8.2, J22.1, J24.1, R36.1, R40.1, TP29.1, U8.3, U8.8, U8.9
GND8: C9.2, J25.1, J27.1, R41.1, R45.1, TP33.1, U9.3, U9.8, U9.9
GND9: C10.2, J28.1, J30.1, R46.1, R50.1, TP37.1, U10.3, U10.8, U10.9
GND10: C11.2, J31.1, J33.1, R51.1, R55.1, TP41.1, U11.3, U11.8, U11.9
GND11: C12.2, J34.1, J36.1, R56.1, R60.1, TP45.1, U12.3, U12.8, U12.9
GND12: C13.2, J37.1, J39.1, R61.1, R65.1, TP49.1, U13.3, U13.8, U13.9
GND13: C14.2, J40.1, J42.1, R66.1, R70.1, TP53.1, U14.3, U14.8, U14.9
GND14: C15.2, J43.1, J45.1, R71.1, R75.1, TP57.1, U15.3, U15.8, U15.9
GND15: C16.2, J46.1, J48.1, R76.1, R80.1, TP61.1, U16.3, U16.8, U16.9
GND16: C17.2, J49.1, J51.1, R81.1, R85.1, TP65.1, U17.3, U17.8, U17.9
GND17: C18.2, J52.1, J54.1, R86.1, R90.1, TP69.1, U18.3, U18.8, U18.9
GND18: C19.2, J55.1, J57.1, R91.1, R95.1, TP73.1, U19.3, U19.8, U19.9
GND19: C20.2, J58.1, J60.1, R96.1, R100.1, TP77.1, U20.3, U20.8, U20.9
GND20: C21.2, J61.1, J63.1, R101.1, R105.1, TP81.1, U21.3, U21.8, U21.9
GND21: C22.2, J64.1, J66.1, R106.1, R110.1, TP85.1, U22.3, U22.8, U22.9
GND22: C23.2, J67.1, J69.1, R111.1, R115.1, TP89.1, U23.3, U23.8, U23.9
GND23: C24.2, J70.1, J72.1, R116.1, R120.1, TP93.1, U24.3, U24.8, U24.9
GND24: C25.2, J73.1, J75.1, R121.1, R125.1, TP97.1, U25.3, U25.8, U25.9
GND25: C26.2, J76.1, J78.1, R126.1, R130.1, TP101.1, U26.3, U26.8, U26.9
GND26: C27.2, J79.1, J81.1, R131.1, R135.1, TP105.1, U27.3, U27.8, U27.9
GND27: C28.2, J82.1, J84.1, R136.1, R140.1, TP109.1, U28.3, U28.8, U28.9
GND28: C29.2, J85.1, J87.1, R141.1, R145.1, TP113.1, U29.3, U29.8, U29.9
GND29: C30.2, J88.1, J90.1, R146.1, R150.1, TP117.1, U30.3, U30.8, U30.9
GND30: C31.2, J91.1, J93.1, R151.1, R155.1, TP121.1, U31.3, U31.8, U31.9
GND31: C32.2, J94.1, J96.1, R156.1, R160.1, TP125.1, U32.3, U32.8, U32.9
GND32: C33.2, J97.1, J99.1, R161.1, R165.1, TP129.1, U33.3, U33.8, U33.9
GND33: C34.2, J100.1, J102.1, R166.1, R170.1, TP133.1, U34.3, U34.8, U34.9
GND34: C35.2, J103.1, J105.1, R171.1, R175.1, TP137.1, U35.3, U35.8, U35.9
GND35: C36.2, J106.1, J108.1, R176.1, R180.1, TP141.1, U36.3, U36.8, U36.9
GND36: C37.2, J109.1, J111.1, R181.1, R185.1, TP145.1, U37.3, U37.8, U37.9
GND37: C38.2, J112.1, J114.1, R186.1, R190.1, TP149.1, U38.3, U38.8, U38.9
GND38: C39.2, J115.1, J117.1, R191.1, R195.1, TP153.1, U39.3, U39.8, U39.9
GND39: C40.2, J118.1, J120.1, R196.1, R200.1, TP157.1, U40.3, U40.8, U40.9
GND40: C41.2, J121.1, J123.1, R201.1, R205.1, TP161.1, U41.3, U41.8, U41.9
GND41: C42.2, J124.1, J126.1, R206.1, R210.1, TP165.1, U42.3, U42.8, U42.9
GND42: C43.2, J127.1, J129.1, R211.1, R215.1, TP169.1, U43.3, U43.8, U43.9
GND43: C44.2, J130.1, J132.1, R216.1, R220.1, TP173.1, U44.3, U44.8, U44.9
GND44: C45.2, J133.1, J135.1, R221.1, R225.1, TP177.1, U45.3, U45.8, U45.9
GND45: C46.2, J136.1, J138.1, R226.1, R230.1, TP181.1, U46.3, U46.8, U46.9
GND46: C47.2, J139.1, J141.1, R231.1, R235.1, TP185.1, U47.3, U47.8, U47.9
GND47: C48.2, J142.1, J144.1, R236.1, R240.1, TP189.1, U48.3, U48.8, U48.9
GND48: C49.2, J145.1, J147.1, R241.1, R245.1, TP193.1, U49.3, U49.8, U49.9
GND49: C50.2, J148.1, J150.1, R246.1, R250.1, TP197.1, U50.3, U50.8, U50.9
GND50: C51.2, J151.1, J153.1, R251.1, R255.1, TP201.1, U51.3, U51.8, U51.9
GND51: C52.2, J154.1, J156.1, R256.1, R260.1, TP205.1, U52.3, U52.8, U52.9
GND52: C53.2, J157.1, J159.1, R261.1, R265.1, TP209.1, U53.3, U53.8, U53.9
GND53: C54.2, J160.1, J162.1, R266.1, R270.1, TP213.1, U54.3, U54.8, U54.9
GND54: C55.2, J163.1, J165.1, R271.1, R275.1, TP217.1, U55.3, U55.8, U55.9
GND55: C56.2, J166.1, J168.1, R276.1, R280.1, TP221.1, U56.3, U56.8, U56.9
GND56: C57.2, J169.1, J171.1, R281.1, R285.1, TP225.1, U57.3, U57.8, U57.9
GND57: C58.2, J172.1, J174.1, R286.1, R290.1, TP229.1, U58.3, U58.8, U58.9
GND58: C59.2, J175.1, J177.1, R291.1, R295.1, TP233.1, U59.3, U59.8, U59.9
GND59: C60.2, J178.1, J180.1, R296.1, R300.1, TP237.1, U60.3, U60.8, U60.9
GND60: C61.2, J181.1, J183.1, R301.1, R305.1, TP241.1, U61.3, U61.8, U61.9
GND61: C62.2, J184.1, J186.1, R306.1, R310.1, TP245.1, U62.3, U62.8, U62.9
GND62: C63.2, J187.1, J189.1, R311.1, R315.1, TP249.1, U63.3, U63.8, U63.9
GND63: C64.2, J190.1, J192.1, R316.1, R320.1, TP253.1, U64.3, U64.8, U64.9
INT: J2.1, U1.7
INT1: J5.1, U2.7
INT2: J8.1, U3.7
INT3: J11.1, U4.7
INT4: J14.1, U5.7
INT5: J17.1, U6.7
INT6: J20.1, U7.7
INT7: J23.1, U8.7
INT8: J26.1, U9.7
INT9: J29.1, U10.7
INT10: J32.1, U11.7
INT11: J35.1, U12.7
INT12: J38.1, U13.7
INT13: J41.1, U14.7
INT14: J44.1, U15.7
INT15: J47.1, U16.7
INT16: J50.1, U17.7
INT17: J53.1, U18.7
INT18: J56.1, U19.7
INT19: J59.1, U20.7
INT20: J62.1, U21.7
INT21: J65.1, U22.7
INT22: J68.1, U23.7
INT23: J71.1, U24.7
INT24: J74.1, U25.7
INT25: J77.1, U26.7
INT26: J80.1, U27.7
INT27: J83.1, U28.7
INT28: J86.1, U29.7
INT29: J89.1, U30.7
INT30: J92.1, U31.7
INT31: J95.1, U32.7
INT32: J98.1, U33.7
INT33: J101.1, U34.7
INT34: J104.1, U35.7
INT35: J107.1, U36.7
INT36: J110.1, U37.7
INT37: J113.1, U38.7
INT38: J116.1, U39.7
INT39: J119.1, U40.7
INT40: J122.1, U41.7
INT41: J125.1, U42.7
INT42: J128.1, U43.7
INT43: J131.1, U44.7
INT44: J134.1, U45.7
INT45: J137.1, U46.7
INT46: J140.1, U47.7
INT47: J143.1, U48.7
INT48: J146.1, U49.7
INT49: J149.1, U50.7
INT50: J152.1, U51.7
INT51: J155.1, U52.7
INT52: J158.1, U53.7
INT53: J161.1, U54.7
INT54: J164.1, U55.7
INT55: J167.1, U56.7
INT56: J170.1, U57.7
INT57: J173.1, U58.7
INT58: J176.1, U59.7
INT59: J179.1, U60.7
INT60: J182.1, U61.7
INT61: J185.1, U62.7
INT62: J188.1, U63.7
INT63: J191.1, U64.7
unnamed: JP1.3, R3.1
unnamed: JP1.1, R4.2
unnamed: JP2.1, R2.1
unnamed: JP2.3, R1.2
unnamed: D1.A, JP3.1
unnamed: D1.C, R5.2
unnamed: D2.A, JP4.1
unnamed: D2.C, R6.2
unnamed: JP5.1, R8.1
unnamed: JP5.3, R7.2
unnamed: JP6.3, R9.1
unnamed: JP6.1, R10.2
unnamed: D3.A, JP7.1
unnamed: D3.C, R11.2
unnamed: JP8.1, R13.1
unnamed: JP8.3, R12.2
unnamed: JP9.3, R14.1
unnamed: JP9.1, R15.2
unnamed: D4.A, JP10.1
unnamed: D4.C, R16.2
unnamed: JP11.1, R18.1
unnamed: JP11.3, R17.2
unnamed: JP12.3, R19.1
unnamed: JP12.1, R20.2
unnamed: D5.A, JP13.1
unnamed: D5.C, R21.2
unnamed: JP14.1, R23.1
unnamed: JP14.3, R22.2
unnamed: JP15.3, R24.1
unnamed: JP15.1, R25.2
unnamed: D6.A, JP16.1
unnamed: D6.C, R26.2
unnamed: JP17.1, R28.1
unnamed: JP17.3, R27.2
unnamed: JP18.3, R29.1
unnamed: JP18.1, R30.2
unnamed: D7.A, JP19.1
unnamed: D7.C, R31.2
unnamed: JP20.1, R33.1
unnamed: JP20.3, R32.2
unnamed: JP21.3, R34.1
unnamed: JP21.1, R35.2
unnamed: D8.A, JP22.1
unnamed: D8.C, R36.2
unnamed: JP23.1, R38.1
unnamed: JP23.3, R37.2
unnamed: JP24.3, R39.1
unnamed: JP24.1, R40.2
unnamed: D9.A, JP25.1
unnamed: D9.C, R41.2
unnamed: JP26.1, R43.1
unnamed: JP26.3, R42.2
unnamed: JP27.3, R44.1
unnamed: JP27.1, R45.2
unnamed: D10.A, JP28.1
unnamed: D10.C, R46.2
unnamed: JP29.1, R48.1
unnamed: JP29.3, R47.2
unnamed: JP30.3, R49.1
unnamed: JP30.1, R50.2
unnamed: D11.A, JP31.1
unnamed: D11.C, R51.2
unnamed: JP32.1, R53.1
unnamed: JP32.3, R52.2
unnamed: JP33.3, R54.1
unnamed: JP33.1, R55.2
unnamed: D12.A, JP34.1
unnamed: D12.C, R56.2
unnamed: JP35.1, R58.1
unnamed: JP35.3, R57.2
unnamed: JP36.3, R59.1
unnamed: JP36.1, R60.2
unnamed: D13.A, JP37.1
unnamed: D13.C, R61.2
unnamed: JP38.1, R63.1
unnamed: JP38.3, R62.2
unnamed: JP39.3, R64.1
unnamed: JP39.1, R65.2
unnamed: D14.A, JP40.1
unnamed: D14.C, R66.2
unnamed: JP41.1, R68.1
unnamed: JP41.3, R67.2
unnamed: JP42.3, R69.1
unnamed: JP42.1, R70.2
unnamed: D15.A, JP43.1
unnamed: D15.C, R71.2
unnamed: JP44.1, R73.1
unnamed: JP44.3, R72.2
unnamed: JP45.3, R74.1
unnamed: JP45.1, R75.2
unnamed: D16.A, JP46.1
unnamed: D16.C, R76.2
unnamed: JP47.1, R78.1
unnamed: JP47.3, R77.2
unnamed: JP48.3, R79.1
unnamed: JP48.1, R80.2
unnamed: D17.A, JP49.1
unnamed: D17.C, R81.2
unnamed: JP50.1, R83.1
unnamed: JP50.3, R82.2
unnamed: JP51.3, R84.1
unnamed: JP51.1, R85.2
unnamed: D18.A, JP52.1
unnamed: D18.C, R86.2
unnamed: JP53.1, R88.1
unnamed: JP53.3, R87.2
unnamed: JP54.3, R89.1
unnamed: JP54.1, R90.2
unnamed: D19.A, JP55.1
unnamed: D19.C, R91.2
unnamed: JP56.1, R93.1
unnamed: JP56.3, R92.2
unnamed: JP57.3, R94.1
unnamed: JP57.1, R95.2
unnamed: D20.A, JP58.1
unnamed: D20.C, R96.2
unnamed: JP59.1, R98.1
unnamed: JP59.3, R97.2
unnamed: JP60.3, R99.1
unnamed: JP60.1, R100.2
unnamed: D21.A, JP61.1
unnamed: D21.C, R101.2
unnamed: JP62.1, R103.1
unnamed: JP62.3, R102.2
unnamed: JP63.3, R104.1
unnamed: JP63.1, R105.2
unnamed: D22.A, JP64.1
unnamed: D22.C, R106.2
unnamed: JP65.1, R108.1
unnamed: JP65.3, R107.2
unnamed: JP66.3, R109.1
unnamed: JP66.1, R110.2
unnamed: D23.A, JP67.1
unnamed: D23.C, R111.2
unnamed: JP68.1, R113.1
unnamed: JP68.3, R112.2
unnamed: JP69.3, R114.1
unnamed: JP69.1, R115.2
unnamed: D24.A, JP70.1
unnamed: D24.C, R116.2
unnamed: JP71.1, R118.1
unnamed: JP71.3, R117.2
unnamed: JP72.3, R119.1
unnamed: JP72.1, R120.2
unnamed: D25.A, JP73.1
unnamed: D25.C, R121.2
unnamed: JP74.1, R123.1
unnamed: JP74.3, R122.2
unnamed: JP75.3, R124.1
unnamed: JP75.1, R125.2
unnamed: D26.A, JP76.1
unnamed: D26.C, R126.2
unnamed: JP77.1, R128.1
unnamed: JP77.3, R127.2
unnamed: JP78.3, R129.1
unnamed: JP78.1, R130.2
unnamed: D27.A, JP79.1
unnamed: D27.C, R131.2
unnamed: JP80.1, R133.1
unnamed: JP80.3, R132.2
unnamed: JP81.3, R134.1
unnamed: JP81.1, R135.2
unnamed: D28.A, JP82.1
unnamed: D28.C, R136.2
unnamed: JP83.1, R138.1
unnamed: JP83.3, R137.2
unnamed: JP84.3, R139.1
unnamed: JP84.1, R140.2
unnamed: D29.A, JP85.1
unnamed: D29.C, R141.2
unnamed: JP86.1, R143.1
unnamed: JP86.3, R142.2
unnamed: JP87.3, R144.1
unnamed: JP87.1, R145.2
unnamed: D30.A, JP88.1
unnamed: D30.C, R146.2
unnamed: JP89.1, R148.1
unnamed: JP89.3, R147.2
unnamed: JP90.3, R149.1
unnamed: JP90.1, R150.2
unnamed: D31.A, JP91.1
unnamed: D31.C, R151.2
unnamed: JP92.1, R153.1
unnamed: JP92.3, R152.2
unnamed: JP93.3, R154.1
unnamed: JP93.1, R155.2
unnamed: D32.A, JP94.1
unnamed: D32.C, R156.2
unnamed: JP95.1, R158.1
unnamed: JP95.3, R157.2
unnamed: JP96.3, R159.1
unnamed: JP96.1, R160.2
unnamed: D33.A, JP97.1
unnamed: D33.C, R161.2
unnamed: JP98.1, R163.1
unnamed: JP98.3, R162.2
unnamed: JP99.3, R164.1
unnamed: JP99.1, R165.2
unnamed: D34.A, JP100.1
unnamed: D34.C, R166.2
unnamed: JP101.1, R168.1
unnamed: JP101.3, R167.2
unnamed: JP102.3, R169.1
unnamed: JP102.1, R170.2
unnamed: D35.A, JP103.1
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

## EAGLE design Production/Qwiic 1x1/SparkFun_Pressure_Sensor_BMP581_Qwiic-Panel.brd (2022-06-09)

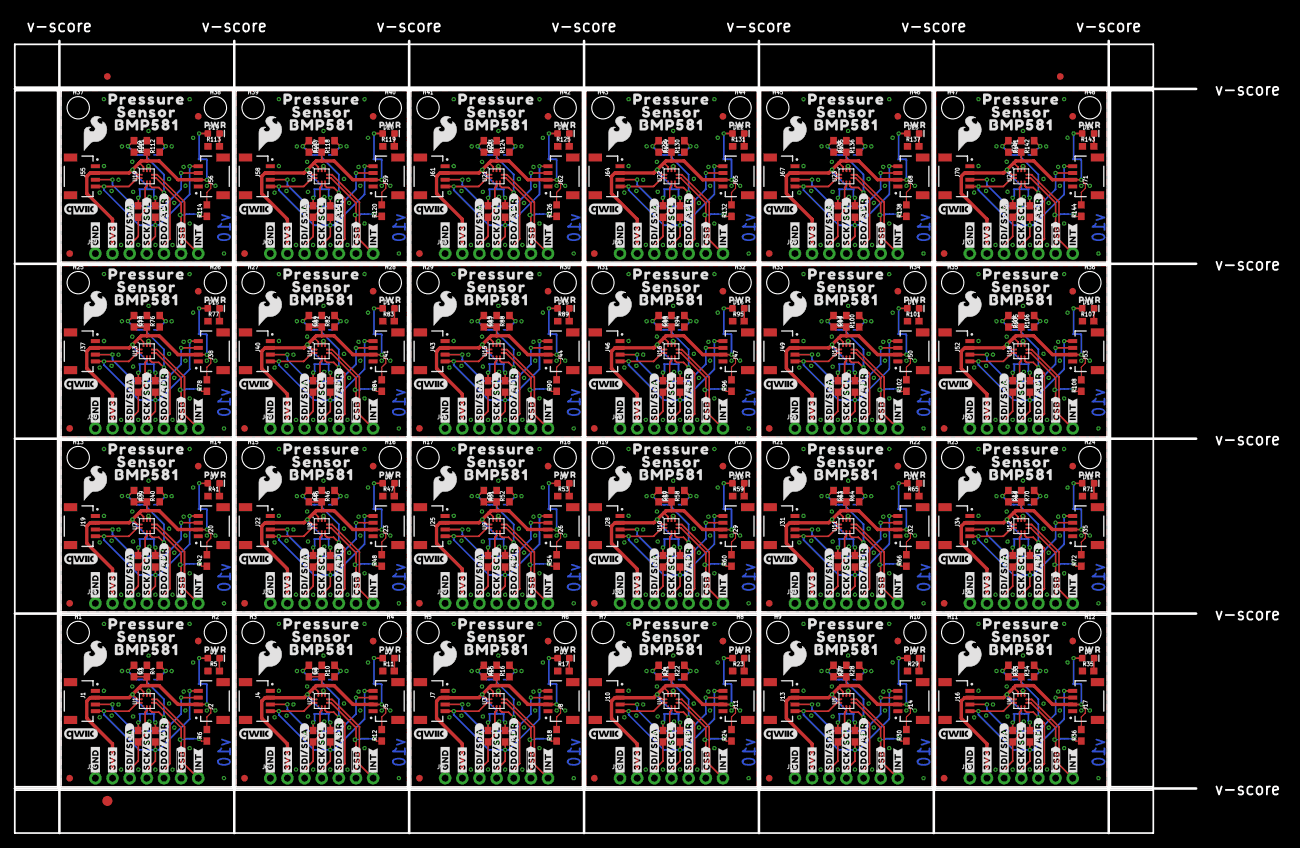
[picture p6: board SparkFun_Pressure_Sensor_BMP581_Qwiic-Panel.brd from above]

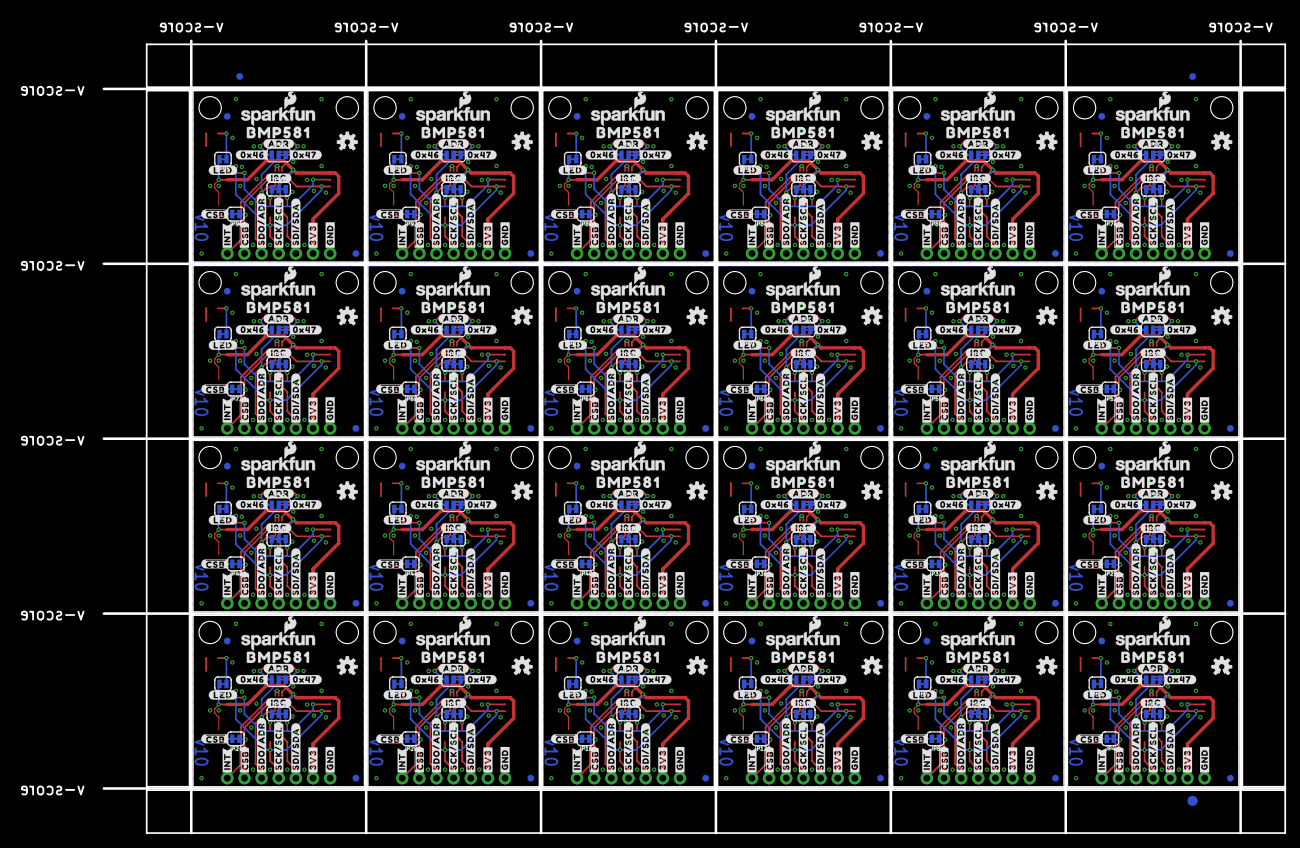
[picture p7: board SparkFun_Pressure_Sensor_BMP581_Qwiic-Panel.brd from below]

Board: 2 copper layers, 175.0 x 117.3 mm, 1230 parts (531 on the bottom side), 336 nets.

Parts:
C1, C2, C3, C4, C5, C6, C7, C8, C9, C10, C11, C12, C13, C14, C15, C16, C17, C18, C19, C20, C21, C22, C23, C24: 0.1uF; 0603
D1, D2, D3, D4, D5, D6, D7, D8, D9, D10, D11, D12, D13, D14, D15, D16, D17, D18, D19, D20, D21, D22, D23, D24: RED; LED-0603
E$1, E$2, E$3, E$4: FIDUCIAL-1X2
E$5, E$6: FIDUCIAL-1.5X3
FD1, FD2, FD3, FD4, FD5, FD6, FD7, FD8, FD9, FD10, FD11, FD12, FD13, FD14, FD15, FD16, FD17, FD18, FD19, FD20, FD21, FD22, FD23, FD24, FD25, FD26, FD27, FD28, FD29, FD30, FD31, FD32, FD33, FD34, FD35, FD36, FD37, FD38, FD39, FD40, FD41, FD42, FD43, FD44, FD45, FD46, FD47, FD48, FD49, FD50, FD51, FD52, FD53, FD54, FD55, FD56, FD57, FD58, FD59, FD60, FD61, FD62, FD63, FD64, FD65, FD66, FD67, FD68, FD69, FD70, FD71, FD72, FD73, FD74, FD75, FD76, FD77, FD78, FD79, FD80, FD81, FD82, FD83, FD84, FD85, FD86, FD87, FD88, FD89, FD90, FD91, FD92, FD93, FD94, FD95, FD96: FIDUCIAL1X2; FIDUCIAL-1X2
H1, H2, H3, H4, H5, H6, H7, H8, H9, H10, H11, H12, H13, H14, H15, H16, H17, H18, H19, H20, H21, H22, H23, H24, H25, H26, H27, H28, H29, H30, H31, H32, H33, H34, H35, H36, H37, H38, H39, H40, H41, H42, H43, H44, H45, H46, H47, H48: STAND-OFF
J1, J2, J4, J5, J7, J8, J10, J11, J13, J14, J16, J17, J19, J20, J22, J23, J25, J26, J28, J29, J31, J32, J34, J35, J37, J38, J40, J41, J43, J44, J46, J47, J49, J50, J52, J53, J55, J56, J58, J59, J61, J62, J64, J65, J67, J68, J70, J71: QWIIC_RIGHT_ANGLE; JST04_1MM_RA
J3, J6, J9, J12, J15, J18, J21, J24, J27, J30, J33, J36, J39, J42, J45, J48, J51, J54, J57, J60, J63, J66, J69, J72: 1X07_NO_SILK
JP1, JP5, JP9, JP13, JP17, JP21, JP25, JP29, JP33, JP37, JP41, JP45, JP49, JP53, JP57, JP61, JP65, JP69, JP73, JP77, JP81, JP85, JP89, JP93: ADR; SMT-JUMPER_3_1-NC_TRACE_SILK
JP2, JP6, JP10, JP14, JP18, JP22, JP26, JP30, JP34, JP38, JP42, JP46, JP50, JP54, JP58, JP62, JP66, JP70, JP74, JP78, JP82, JP86, JP90, JP94: I2C; SMT-JUMPER_3_2-NC_TRACE_SILK
JP3, JP7, JP11, JP15, JP19, JP23, JP27, JP31, JP35, JP39, JP43, JP47, JP51, JP55, JP59, JP63, JP67, JP71, JP75, JP79, JP83, JP87, JP91, JP95: LED; SMT-JUMPER_2_NC_TRACE_SILK
JP4, JP8, JP12, JP16, JP20, JP24, JP28, JP32, JP36, JP40, JP44, JP48, JP52, JP56, JP60, JP64, JP68, JP72, JP76, JP80, JP84, JP88, JP92, JP96: !CSB!; SMT-JUMPER_2_NC_TRACE_SILK
LOGO1, LOGO5, LOGO9, LOGO13, LOGO17, LOGO21, LOGO25, LOGO29, LOGO33, LOGO37, LOGO41, LOGO45, LOGO49, LOGO53, LOGO57, LOGO61, LOGO65, LOGO69, LOGO73, LOGO77, LOGO81, LOGO85, LOGO89, LOGO93: OSHW-LOGOS; OSHW-LOGO-S
LOGO2, LOGO6, LOGO10, LOGO14, LOGO18, LOGO22, LOGO26, LOGO30, LOGO34, LOGO38, LOGO42, LOGO46, LOGO50, LOGO54, LOGO58, LOGO62, LOGO66, LOGO70, LOGO74, LOGO78, LOGO82, LOGO86, LOGO90, LOGO94: SFE_LOGO_FLAME.2_INCH; SFE_LOGO_FLAME_.2
LOGO3, LOGO7, LOGO11, LOGO15, LOGO19, LOGO23, LOGO27, LOGO31, LOGO35, LOGO39, LOGO43, LOGO47, LOGO51, LOGO55, LOGO59, LOGO63, LOGO67, LOGO71, LOGO75, LOGO79, LOGO83, LOGO87, LOGO91, LOGO95: QWIIC_LOGO_5MM; QWIIC_5MM
LOGO4, LOGO8, LOGO12, LOGO16, LOGO20, LOGO24, LOGO28, LOGO32, LOGO36, LOGO40, LOGO44, LOGO48, LOGO52, LOGO56, LOGO60, LOGO64, LOGO68, LOGO72, LOGO76, LOGO80, LOGO84, LOGO88, LOGO92, LOGO96: SFE_LOGO_NAME_FLAME.1_INCH; SFE_LOGO_NAME_FLAME_.1
R1, R2, R7, R8, R13, R14, R19, R20, R25, R26, R31, R32, R37, R38, R43, R44, R49, R50, R55, R56, R61, R62, R67, R68, R73, R74, R79, R80, R85, R86, R91, R92, R97, R98, R103, R104, R109, R110, R115, R116, R121, R122, R127, R128, R133, R134, R139, R140: 2.2k; 0603
R3, R4, R6, R9, R10, R12, R15, R16, R18, R21, R22, R24, R27, R28, R30, R33, R34, R36, R39, R40, R42, R45, R46, R48, R51, R52, R54, R57, R58, R60, R63, R64, R66, R69, R70, R72, R75, R76, R78, R81, R82, R84, R87, R88, R90, R93, R94, R96, R99, R100, R102, R105, R106, R108, R111, R112, R114, R117, R118, R120, R123, R124, R126, R129, R130, R132, R135, R136, R138, R141, R142, R144: 10k; 0603
R5, R11, R17, R23, R29, R35, R41, R47, R53, R59, R65, R71, R77, R83, R89, R95, R101, R107, R113, R119, R125, R131, R137, R143: 1k; 0603
U1, U2, U3, U4, U5, U6, U7, U8, U9, U10, U11, U12, U13, U14, U15, U16, U17, U18, U19, U20, U21, U22, U23, U24: BMP581
U$1, U$22, U$27, U$50, U$53, U$75, U$78, U$100, U$103, U$125, U$128, U$150, U$153, U$175, U$178, U$200, U$203, U$225, U$228, U$250, U$253, U$275, U$278, U$300, U$303, U$325, U$328, U$350, U$353, U$375, U$378, U$400, U$403, U$425, U$428, U$450, U$453, U$475, U$478, U$500, U$503, U$525, U$528, U$550, U$553, U$575, U$578, U$600: BMP5810
U$2, U$3, U$29, U$30, U$54, U$55, U$79, U$80, U$104, U$105, U$129, U$130, U$154, U$155, U$179, U$180, U$204, U$205, U$229, U$230, U$254, U$255, U$279, U$280, U$304, U$305, U$329, U$330, U$354, U$355, U$379, U$380, U$404, U$405, U$429, U$430, U$454, U$455, U$479, U$480, U$504, U$505, U$529, U$530, U$554, U$555, U$579, U$580: #GND#0
U$4, U$20, U$39, U$40, U$64, U$65, U$89, U$90, U$114, U$115, U$139, U$140, U$164, U$165, U$189, U$190, U$214, U$215, U$239, U$240, U$264, U$265, U$289, U$290, U$314, U$315, U$339, U$340, U$364, U$365, U$389, U$390, U$414, U$415, U$439, U$440, U$464, U$465, U$489, U$490, U$514, U$515, U$539, U$540, U$564, U$565, U$589, U$590: #3V3#0
U$5, U$6, U$31, U$32, U$56, U$57, U$81, U$82, U$106, U$107, U$131, U$132, U$156, U$157, U$181, U$182, U$206, U$207, U$231, U$232, U$256, U$257, U$281, U$282, U$306, U$307, U$331, U$332, U$356, U$357, U$381, U$382, U$406, U$407, U$431, U$432, U$456, U$457, U$481, U$482, U$506, U$507, U$531, U$532, U$556, U$557, U$581, U$582: #SDI#SDA#0
U$7, U$8, U$33, U$34, U$58, U$59, U$83, U$84, U$108, U$109, U$133, U$134, U$158, U$159, U$183, U$184, U$208, U$209, U$233, U$234, U$258, U$259, U$283, U$284, U$308, U$309, U$333, U$334, U$358, U$359, U$383, U$384, U$408, U$409, U$433, U$434, U$458, U$459, U$483, U$484, U$508, U$509, U$533, U$534, U$558, U$559, U$583, U$584: #SCK#SCL#0
U$9, U$10, U$35, U$36, U$60, U$61, U$85, U$86, U$110, U$111, U$135, U$136, U$160, U$161, U$185, U$186, U$210, U$211, U$235, U$236, U$260, U$261, U$285, U$286, U$310, U$311, U$335, U$336, U$360, U$361, U$385, U$386, U$410, U$411, U$435, U$436, U$460, U$461, U$485, U$486, U$510, U$511, U$535, U$536, U$560, U$561, U$585, U$586: #SDO#ADR#0
U$11, U$45, U$70, U$95, U$120, U$145, U$170, U$195, U$220, U$245, U$270, U$295, U$320, U$345, U$370, U$395, U$420, U$445, U$470, U$495, U$520, U$545, U$570, U$595: #I2C#0
U$12, U$46, U$71, U$96, U$121, U$146, U$171, U$196, U$221, U$246, U$271, U$296, U$321, U$346, U$371, U$396, U$421, U$446, U$471, U$496, U$521, U$546, U$571, U$596: #0X46#0
U$13, U$14, U$37, U$38, U$62, U$63, U$87, U$88, U$112, U$113, U$137, U$138, U$162, U$163, U$187, U$188, U$212, U$213, U$237, U$238, U$262, U$263, U$287, U$288, U$312, U$313, U$337, U$338, U$362, U$363, U$387, U$388, U$412, U$413, U$437, U$438, U$462, U$463, U$487, U$488, U$512, U$513, U$537, U$538, U$562, U$563, U$587, U$588: #INT#0
U$15, U$47, U$72, U$97, U$122, U$147, U$172, U$197, U$222, U$247, U$272, U$297, U$322, U$347, U$372, U$397, U$422, U$447, U$472, U$497, U$522, U$547, U$572, U$597: #0X47#0
U$16, U$48, U$73, U$98, U$123, U$148, U$173, U$198, U$223, U$248, U$273, U$298, U$323, U$348, U$373, U$398, U$423, U$448, U$473, U$498, U$523, U$548, U$573, U$598: PWR0
U$17, U$43, U$68, U$93, U$118, U$143, U$168, U$193, U$218, U$243, U$268, U$293, U$318, U$343, U$368, U$393, U$418, U$443, U$468, U$493, U$518, U$543, U$568, U$593: #ADR#0
U$18, U$49, U$74, U$99, U$124, U$149, U$174, U$199, U$224, U$249, U$274, U$299, U$324, U$349, U$374, U$399, U$424, U$449, U$474, U$499, U$524, U$549, U$574, U$599: ##CSB##1
U$19, U$44, U$69, U$94, U$119, U$144, U$169, U$194, U$219, U$244, U$269, U$294, U$319, U$344, U$369, U$394, U$419, U$444, U$469, U$494, U$519, U$544, U$569, U$594: #LED#0
U$21, U$23, U$51, U$76, U$101, U$126, U$151, U$176, U$201, U$226, U$251, U$276, U$301, U$326, U$351, U$376, U$401, U$426, U$451, U$476, U$501, U$526, U$551, U$576: PRESSURE0
U$24, U$26, U$52, U$77, U$102, U$127, U$152, U$177, U$202, U$227, U$252, U$277, U$302, U$327, U$352, U$377, U$402, U$427, U$452, U$477, U$502, U$527, U$552, U$577: SENSOR0
U$25, U$28, U$41, U$42, U$66, U$67, U$91, U$92, U$116, U$117, U$141, U$142, U$166, U$167, U$191, U$192, U$216, U$217, U$241, U$242, U$266, U$267, U$291, U$292, U$316, U$317, U$341, U$342, U$366, U$367, U$391, U$392, U$416, U$417, U$441, U$442, U$466, U$467, U$491, U$492, U$516, U$517, U$541, U$542, U$566, U$567, U$591, U$592: ##CSB##0

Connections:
!CSB!: J3.6, JP4.1, U1.6
!CSB!1: J6.6, JP8.1, U2.6
!CSB!2: J9.6, JP12.1, U3.6
!CSB!3: J12.6, JP16.1, U4.6
!CSB!4: J15.6, JP20.1, U5.6
!CSB!5: J18.6, JP24.1, U6.6
!CSB!6: J21.6, JP28.1, U7.6
!CSB!7: J24.6, JP32.1, U8.6
!CSB!8: J27.6, JP36.1, U9.6
!CSB!9: J30.6, JP40.1, U10.6
!CSB!10: J33.6, JP44.1, U11.6
!CSB!11: J36.6, JP48.1, U12.6
!CSB!12: J39.6, JP52.1, U13.6
!CSB!13: J42.6, JP56.1, U14.6
!CSB!14: J45.6, JP60.1, U15.6
!CSB!15: J48.6, JP64.1, U16.6
!CSB!16: J51.6, JP68.1, U17.6
!CSB!17: J54.6, JP72.1, U18.6
!CSB!18: J57.6, JP76.1, U19.6
!CSB!19: J60.6, JP80.1, U20.6
!CSB!20: J63.6, JP84.1, U21.6
!CSB!21: J66.6, JP88.1, U22.6
!CSB!22: J69.6, JP92.1, U23.6
!CSB!23: J72.6, JP96.1, U24.6
GND: C1.2, J1.1, J2.1, J3.1, R4.1, R5.1, U1.3, U1.8, U1.9
GND1: C2.2, J4.1, J5.1, J6.1, R10.1, R11.1, U2.3, U2.8, U2.9
GND2: C3.2, J7.1, J8.1, J9.1, R16.1, R17.1, U3.3, U3.8, U3.9
GND3: C4.2, J10.1, J11.1, J12.1, R22.1, R23.1, U4.3, U4.8, U4.9
GND4: C5.2, J13.1, J14.1, J15.1, R28.1, R29.1, U5.3, U5.8, U5.9
GND5: C6.2, J16.1, J17.1, J18.1, R34.1, R35.1, U6.3, U6.8, U6.9
GND6: C7.2, J19.1, J20.1, J21.1, R40.1, R41.1, U7.3, U7.8, U7.9
GND7: C8.2, J22.1, J23.1, J24.1, R46.1, R47.1, U8.3, U8.8, U8.9
GND8: C9.2, J25.1, J26.1, J27.1, R52.1, R53.1, U9.3, U9.8, U9.9
GND9: C10.2, J28.1, J29.1, J30.1, R58.1, R59.1, U10.3, U10.8, U10.9
GND10: C11.2, J31.1, J32.1, J33.1, R64.1, R65.1, U11.3, U11.8, U11.9
GND11: C12.2, J34.1, J35.1, J36.1, R70.1, R71.1, U12.3, U12.8, U12.9
GND12: C13.2, J37.1, J38.1, J39.1, R76.1, R77.1, U13.3, U13.8, U13.9
GND13: C14.2, J40.1, J41.1, J42.1, R82.1, R83.1, U14.3, U14.8, U14.9
GND14: C15.2, J43.1, J44.1, J45.1, R88.1, R89.1, U15.3, U15.8, U15.9
GND15: C16.2, J46.1, J47.1, J48.1, R94.1, R95.1, U16.3, U16.8, U16.9
GND16: C17.2, J49.1, J50.1, J51.1, R100.1, R101.1, U17.3, U17.8, U17.9
GND17: C18.2, J52.1, J53.1, J54.1, R106.1, R107.1, U18.3, U18.8, U18.9
GND18: C19.2, J55.1, J56.1, J57.1, R112.1, R113.1, U19.3, U19.8, U19.9
GND19: C20.2, J58.1, J59.1, J60.1, R118.1, R119.1, U20.3, U20.8, U20.9
GND20: C21.2, J61.1, J62.1, J63.1, R124.1, R125.1, U21.3, U21.8, U21.9
GND21: C22.2, J64.1, J65.1, J66.1, R130.1, R131.1, U22.3, U22.8, U22.9
GND22: C23.2, J67.1, J68.1, J69.1, R136.1, R137.1, U23.3, U23.8, U23.9
GND23: C24.2, J70.1, J71.1, J72.1, R142.1, R143.1, U24.3, U24.8, U24.9
INT: J3.7, U1.7
INT1: J6.7, U2.7
INT2: J9.7, U3.7
INT3: J12.7, U4.7
INT4: J15.7, U5.7
INT5: J18.7, U6.7
INT6: J21.7, U7.7
INT7: J24.7, U8.7
INT8: J27.7, U9.7
INT9: J30.7, U10.7
INT10: J33.7, U11.7
INT11: J36.7, U12.7
INT12: J39.7, U13.7
INT13: J42.7, U14.7
INT14: J45.7, U15.7
INT15: J48.7, U16.7
INT16: J51.7, U17.7
INT17: J54.7, U18.7
INT18: J57.7, U19.7
INT19: J60.7, U20.7
INT20: J63.7, U21.7
INT21: J66.7, U22.7
INT22: J69.7, U23.7
INT23: J72.7, U24.7
unnamed: JP1.3, R3.1
unnamed: JP1.1, R4.2
unnamed: JP2.1, R2.1
unnamed: JP2.3, R1.2
unnamed: D1.A, JP3.1
unnamed: D1.C, R5.2
unnamed: JP4.2, R6.1
unnamed: JP5.3, R9.1
unnamed: JP5.1, R10.2
unnamed: JP6.1, R8.1
unnamed: JP6.3, R7.2
unnamed: D2.A, JP7.1
unnamed: D2.C, R11.2
unnamed: JP8.2, R12.1
unnamed: JP9.3, R15.1
unnamed: JP9.1, R16.2
unnamed: JP10.1, R14.1
unnamed: JP10.3, R13.2
unnamed: D3.A, JP11.1
unnamed: D3.C, R17.2
unnamed: JP12.2, R18.1
unnamed: JP13.3, R21.1
unnamed: JP13.1, R22.2
unnamed: JP14.1, R20.1
unnamed: JP14.3, R19.2
unnamed: D4.A, JP15.1
unnamed: D4.C, R23.2
unnamed: JP16.2, R24.1
unnamed: JP17.3, R27.1
unnamed: JP17.1, R28.2
unnamed: JP18.1, R26.1
unnamed: JP18.3, R25.2
unnamed: D5.A, JP19.1
unnamed: D5.C, R29.2
unnamed: JP20.2, R30.1
unnamed: JP21.3, R33.1
unnamed: JP21.1, R34.2
unnamed: JP22.1, R32.1
unnamed: JP22.3, R31.2
unnamed: D6.A, JP23.1
unnamed: D6.C, R35.2
unnamed: JP24.2, R36.1
unnamed: JP25.3, R39.1
unnamed: JP25.1, R40.2
unnamed: JP26.1, R38.1
unnamed: JP26.3, R37.2
unnamed: D7.A, JP27.1
unnamed: D7.C, R41.2
unnamed: JP28.2, R42.1
unnamed: JP29.3, R45.1
unnamed: JP29.1, R46.2
unnamed: JP30.1, R44.1
unnamed: JP30.3, R43.2
unnamed: D8.A, JP31.1
unnamed: D8.C, R47.2
unnamed: JP32.2, R48.1
unnamed: JP33.3, R51.1
unnamed: JP33.1, R52.2
unnamed: JP34.1, R50.1
unnamed: JP34.3, R49.2
unnamed: D9.A, JP35.1
unnamed: D9.C, R53.2
unnamed: JP36.2, R54.1
unnamed: JP37.3, R57.1
unnamed: JP37.1, R58.2
unnamed: JP38.1, R56.1
unnamed: JP38.3, R55.2
unnamed: D10.A, JP39.1
unnamed: D10.C, R59.2
unnamed: JP40.2, R60.1
unnamed: JP41.3, R63.1
unnamed: JP41.1, R64.2
unnamed: JP42.1, R62.1
unnamed: JP42.3, R61.2
unnamed: D11.A, JP43.1
unnamed: D11.C, R65.2
unnamed: JP44.2, R66.1
unnamed: JP45.3, R69.1
unnamed: JP45.1, R70.2
unnamed: JP46.1, R68.1
unnamed: JP46.3, R67.2
unnamed: D12.A, JP47.1
unnamed: D12.C, R71.2
unnamed: JP48.2, R72.1
unnamed: JP49.3, R75.1
unnamed: JP49.1, R76.2
unnamed: JP50.1, R74.1
unnamed: JP50.3, R73.2
unnamed: D13.A, JP51.1
unnamed: D13.C, R77.2
unnamed: JP52.2, R78.1
unnamed: JP53.3, R81.1
unnamed: JP53.1, R82.2
unnamed: JP54.1, R80.1
unnamed: JP54.3, R79.2
unnamed: D14.A, JP55.1
unnamed: D14.C, R83.2
unnamed: JP56.2, R84.1
unnamed: JP57.3, R87.1
unnamed: JP57.1, R88.2
unnamed: JP58.1, R86.1
unnamed: JP58.3, R85.2
unnamed: D15.A, JP59.1
unnamed: D15.C, R89.2
unnamed: JP60.2, R90.1
unnamed: JP61.3, R93.1
unnamed: JP61.1, R94.2
unnamed: JP62.1, R92.1
unnamed: JP62.3, R91.2
unnamed: D16.A, JP63.1
unnamed: D16.C, R95.2
unnamed: JP64.2, R96.1
unnamed: JP65.3, R99.1
unnamed: JP65.1, R100.2
unnamed: JP66.1, R98.1
unnamed: JP66.3, R97.2
unnamed: D17.A, JP67.1
unnamed: D17.C, R101.2
unnamed: JP68.2, R102.1
unnamed: JP69.3, R105.1
unnamed: JP69.1, R106.2
unnamed: JP70.1, R104.1
unnamed: JP70.3, R103.2
unnamed: D18.A, JP71.1
unnamed: D18.C, R107.2
unnamed: JP72.2, R108.1
unnamed: JP73.3, R111.1
unnamed: JP73.1, R112.2
unnamed: JP74.1, R110.1
unnamed: JP74.3, R109.2
unnamed: D19.A, JP75.1
unnamed: D19.C, R113.2
unnamed: JP76.2, R114.1
unnamed: JP77.3, R117.1
unnamed: JP77.1, R118.2
unnamed: JP78.1, R116.1
unnamed: JP78.3, R115.2
unnamed: D20.A, JP79.1
unnamed: D20.C, R119.2
unnamed: JP80.2, R120.1
unnamed: JP81.3, R123.1
unnamed: JP81.1, R124.2
unnamed: JP82.1, R122.1
unnamed: JP82.3, R121.2
unnamed: D21.A, JP83.1
unnamed: D21.C, R125.2
unnamed: JP84.2, R126.1
unnamed: JP85.3, R129.1
unnamed: JP85.1, R130.2
unnamed: JP86.1, R128.1
unnamed: JP86.3, R127.2
unnamed: D22.A, JP87.1
unnamed: D22.C, R131.2
unnamed: JP88.2, R132.1
unnamed: JP89.3, R135.1
unnamed: JP89.1, R136.2
unnamed: JP90.1, R134.1
unnamed: JP90.3, R133.2
unnamed: D23.A, JP91.1
unnamed: D23.C, R137.2
unnamed: JP92.2, R138.1
unnamed: JP93.3, R141.1
unnamed: JP93.1, R142.2
unnamed: JP94.1, R140.1
unnamed: JP94.3, R139.2
unnamed: D24.A, JP95.1
unnamed: D24.C, R143.2
unnamed: JP96.2, R144.1
SCK/SCL: J1.4, J2.4, J3.4, R2.2, U1.2
SCK/SCL1: J4.4, J5.4, J6.4, R8.2, U2.2
SCK/SCL2: J7.4, J8.4, J9.4, R14.2, U3.2
SCK/SCL3: J10.4, J11.4, J12.4, R20.2, U4.2
SCK/SCL4: J13.4, J14.4, J15.4, R26.2, U5.2
SCK/SCL5: J16.4, J17.4, J18.4, R32.2, U6.2
SCK/SCL6: J19.4, J20.4, J21.4, R38.2, U7.2
SCK/SCL7: J22.4, J23.4, J24.4, R44.2, U8.2
SCK/SCL8: J25.4, J26.4, J27.4, R50.2, U9.2
SCK/SCL9: J28.4, J29.4, J30.4, R56.2, U10.2
SCK/SCL10: J31.4, J32.4, J33.4, R62.2, U11.2
SCK/SCL11: J34.4, J35.4, J36.4, R68.2, U12.2
SCK/SCL12: J37.4, J38.4, J39.4, R74.2, U13.2
SCK/SCL13: J40.4, J41.4, J42.4, R80.2, U14.2
SCK/SCL14: J43.4, J44.4, J45.4, R86.2, U15.2
SCK/SCL15: J46.4, J47.4, J48.4, R92.2, U16.2
SCK/SCL16: J49.4, J50.4, J51.4, R98.2, U17.2
SCK/SCL17: J52.4, J53.4, J54.4, R104.2, U18.2
SCK/SCL18: J55.4, J56.4, J57.4, R110.2, U19.2
SCK/SCL19: J58.4, J59.4, J60.4, R116.2, U20.2
SCK/SCL20: J61.4, J62.4, J63.4, R122.2, U21.2
SCK/SCL21: J64.4, J65.4, J66.4, R128.2, U22.2
SCK/SCL22: J67.4, J68.4, J69.4, R134.2, U23.2
SCK/SCL23: J70.4, J71.4, J72.4, R140.2, U24.2
SDI/SDA: J1.3, J2.3, J3.3, R1.1, U1.4
SDI/SDA1: J4.3, J5.3, J6.3, R7.1, U2.4
SDI/SDA2: J7.3, J8.3, J9.3, R13.1, U3.4
SDI/SDA3: J10.3, J11.3, J12.3, R19.1, U4.4
SDI/SDA4: J13.3, J14.3, J15.3, R25.1, U5.4
SDI/SDA5: J16.3, J17.3, J18.3, R31.1, U6.4
SDI/SDA6: J19.3, J20.3, J21.3, R37.1, U7.4
SDI/SDA7: J22.3, J23.3, J24.3, R43.1, U8.4
SDI/SDA8: J25.3, J26.3, J27.3, R49.1, U9.4
SDI/SDA9: J28.3, J29.3, J30.3, R55.1, U10.4
SDI/SDA10: J31.3, J32.3, J33.3, R61.1, U11.4
SDI/SDA11: J34.3, J35.3, J36.3, R67.1, U12.4
SDI/SDA12: J37.3, J38.3, J39.3, R73.1, U13.4
SDI/SDA13: J40.3, J41.3, J42.3, R79.1, U14.4
SDI/SDA14: J43.3, J44.3, J45.3, R85.1, U15.4
SDI/SDA15: J46.3, J47.3, J48.3, R91.1, U16.4
SDI/SDA16: J49.3, J50.3, J51.3, R97.1, U17.4
SDI/SDA17: J52.3, J53.3, J54.3, R103.1, U18.4
SDI/SDA18: J55.3, J56.3, J57.3, R109.1, U19.4
SDI/SDA19: J58.3, J59.3, J60.3, R115.1, U20.4
SDI/SDA20: J61.3, J62.3, J63.3, R121.1, U21.4
SDI/SDA21: J64.3, J65.3, J66.3, R127.1, U22.4
SDI/SDA22: J67.3, J68.3, J69.3, R133.1, U23.4
SDI/SDA23: J70.3, J71.3, J72.3, R139.1, U24.4
SDO/ADR: J3.5, JP1.2, U1.5
SDO/ADR1: J6.5, JP5.2, U2.5
SDO/ADR2: J9.5, JP9.2, U3.5
SDO/ADR3: J12.5, JP13.2, U4.5
SDO/ADR4: J15.5, JP17.2, U5.5
SDO/ADR5: J18.5, JP21.2, U6.5
SDO/ADR6: J21.5, JP25.2, U7.5
SDO/ADR7: J24.5, JP29.2, U8.5
SDO/ADR8: J27.5, JP33.2, U9.5
SDO/ADR9: J30.5, JP37.2, U10.5
SDO/ADR10: J33.5, JP41.2, U11.5
SDO/ADR11: J36.5, JP45.2, U12.5
SDO/ADR12: J39.5, JP49.2, U13.5
SDO/ADR13: J42.5, JP53.2, U14.5
SDO/ADR14: J45.5, JP57.2, U15.5
SDO/ADR15: J48.5, JP61.2, U16.5
SDO/ADR16: J51.5, JP65.2, U17.5
SDO/ADR17: J54.5, JP69.2, U18.5
SDO/ADR18: J57.5, JP73.2, U19.5
SDO/ADR19: J60.5, JP77.2, U20.5
SDO/ADR20: J63.5, JP81.2, U21.5
SDO/ADR21: J66.5, JP85.2, U22.5
SDO/ADR22: J69.5, JP89.2, U23.5
SDO/ADR23: J72.5, JP93.2, U24.5
VDD: C1.1, J1.2, J2.2, J3.2, JP2.2, JP3.2, R3.2, R6.2, U1.1, U1.10
VDD1: C2.1, J4.2, J5.2, J6.2, JP6.2, JP7.2, R9.2, R12.2, U2.1, U2.10
VDD2: C3.1, J7.2, J8.2, J9.2, JP10.2, JP11.2, R15.2, R18.2, U3.1, U3.10
VDD3: C4.1, J10.2, J11.2, J12.2, JP14.2, JP15.2, R21.2, R24.2, U4.1, U4.10
VDD4: C5.1, J13.2, J14.2, J15.2, JP18.2, JP19.2, R27.2, R30.2, U5.1, U5.10
VDD5: C6.1, J16.2, J17.2, J18.2, JP22.2, JP23.2, R33.2, R36.2, U6.1, U6.10
VDD6: C7.1, J19.2, J20.2, J21.2, JP26.2, JP27.2, R39.2, R42.2, U7.1, U7.10
VDD7: C8.1, J22.2, J23.2, J24.2, JP30.2, JP31.2, R45.2, R48.2, U8.1, U8.10
VDD8: C9.1, J25.2, J26.2, J27.2, JP34.2, JP35.2, R51.2, R54.2, U9.1, U9.10
VDD9: C10.1, J28.2, J29.2, J30.2, JP38.2, JP39.2, R57.2, R60.2, U10.1, U10.10
VDD10: C11.1, J31.2, J32.2, J33.2, JP42.2, JP43.2, R63.2, R66.2, U11.1, U11.10
VDD11: C12.1, J34.2, J35.2, J36.2, JP46.2, JP47.2, R69.2, R72.2, U12.1, U12.10
VDD12: C13.1, J37.2, J38.2, J39.2, JP50.2, JP51.2, R75.2, R78.2, U13.1, U13.10
VDD13: C14.1, J40.2, J41.2, J42.2, JP54.2, JP55.2, R81.2, R84.2, U14.1, U14.10
VDD14: C15.1, J43.2, J44.2, J45.2, JP58.2, JP59.2, R87.2, R90.2, U15.1, U15.10
VDD15: C16.1, J46.2, J47.2, J48.2, JP62.2, JP63.2, R93.2, R96.2, U16.1, U16.10
VDD16: C17.1, J49.2, J50.2, J51.2, JP66.2, JP67.2, R99.2, R102.2, U17.1, U17.10
VDD17: C18.1, J52.2, J53.2, J54.2, JP70.2, JP71.2, R105.2, R108.2, U18.1, U18.10
VDD18: C19.1, J55.2, J56.2, J57.2, JP74.2, JP75.2, R111.2, R114.2, U19.1, U19.10
VDD19: C20.1, J58.2, J59.2, J60.2, JP78.2, JP79.2, R117.2, R120.2, U20.1, U20.10
VDD20: C21.1, J61.2, J62.2, J63.2, JP82.2, JP83.2, R123.2, R126.2, U21.1, U21.10
VDD21: C22.1, J64.2, J65.2, J66.2, JP86.2, JP87.2, R129.2, R132.2, U22.1, U22.10
VDD22: C23.1, J67.2, J68.2, J69.2, JP90.2, JP91.2, R135.2, R138.2, U23.1, U23.10
VDD23: C24.1, J70.2, J71.2, J72.2, JP94.2, JP95.2, R141.2, R144.2, U24.1, U24.10

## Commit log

2022-05-24 Create 1x1 board
    Copied from BMP384
    [bmp581.brd, bmp581.sch]
2022-05-24 Create Micro board
    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
    [bmp581.brd, bmp581.sch]
2022-05-25 Design review updates
    Rename files
    Change to v10 (accelerating to reds)
    Fix sensor name in schematic
    Add note to schematic about max wire diameter in Micro PTH connectors
    Update VDD range
    Fix acid trap in Micro
    Move PWR LED to give space
    [SparkFun_Pressure_Sensor_BMP581_Qwiic.brd, SparkFun_Pressure_Sensor_BMP581_Qwiic.sch, SparkFun_Pressure_Sensor_BMP581_Qwiic_Micro.brd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]
2022-05-25 Checklist update
    [SparkFun_Pressure_Sensor_BMP581_Qwiic.brd, SparkFun_Pressure_Sensor_BMP581_Qwiic_Micro.brd]
2022-05-25 Add 1x1 panel
    [SparkFun_Pressure_Sensor_BMP581_Qwiic-Panel.GBL, SparkFun_Pressure_Sensor_BMP581_Qwiic-Panel.GBO, SparkFun_Pressure_Sensor_BMP581_Qwiic-Panel.GBP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]
2022-05-25 Add Micro panel
    [SparkFun_Pressure_Sensor_BMP581_Qwiic_Micro-Panel.brd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]
2022-05-26 Add optional pullup on CSB
    [SparkFun_Pressure_Sensor_BMP581_Qwiic.brd, SparkFun_Pressure_Sensor_BMP581_Qwiic.sch]
2022-05-26 Rename CSB pullup jumper in schematic
    [SparkFun_Pressure_Sensor_BMP581_Qwiic.brd, SparkFun_Pressure_Sensor_BMP581_Qwiic.sch]
2022-05-26 Connect CSB of Micro board to VDD
    [SparkFun_Pressure_Sensor_BMP581_Qwiic_Micro.brd, SparkFun_Pressure_Sensor_BMP581_Qwiic_Micro.sch]
2022-05-26 Add proto gerbers for 1x1 and Micro
    [SparkFun_Pressure_Sensor_BMP581_Qwiic.GBL, SparkFun_Pressure_Sensor_BMP581_Qwiic.GBO, SparkFun_Pressure_Sensor_BMP581_Qwiic.GBP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]
2022-06-09 Design review updates
    Change INT label to fishtail in Micro silk
    Add product name to bottom in 1x1 silk
    Change Micro net labels to be I2C only
    Approve DRC overlaps
    Fix acid trap
    Add note about CSB being tied high in Micro schematic
    [SparkFun_Pressure_Sensor_BMP581_Qwiic.brd, SparkFun_Pressure_Sensor_BMP581_Qwiic_Micro.brd, SparkFun_Pressure_Sensor_BMP581_Qwiic_Micro.sch]
2022-06-09 Add production files for reds
    [SparkFun_Pressure_Sensor_BMP581_Qwiic-Panel.brd, SparkFun_Pressure_Sensor_BMP581_Qwiic.brd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]
2023-03-28 Remove library file
    BMP384 is in SFE Eagle library, update part in design
    [SparkFun_Pressure_Sensor_BMP581_Qwiic.brd, SparkFun_Pressure_Sensor_BMP581_Qwiic.sch, SparkFun_Pressure_Sensor_BMP581_Qwiic_Micro.brd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]

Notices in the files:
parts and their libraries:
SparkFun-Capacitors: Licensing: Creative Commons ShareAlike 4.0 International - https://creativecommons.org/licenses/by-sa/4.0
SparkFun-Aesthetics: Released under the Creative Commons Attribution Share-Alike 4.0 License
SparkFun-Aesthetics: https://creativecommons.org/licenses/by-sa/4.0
